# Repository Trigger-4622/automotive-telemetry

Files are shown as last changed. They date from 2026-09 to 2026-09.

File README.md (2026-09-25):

# Automotive Telemetry

A CAN-bus master and two gauge screens for a 2009 Subaru Legacy B4. The master
reads the car's CAN bus from the OBD port (listening, plus OBD-II and Subaru
SSM2 requests) and broadcasts engineering units over ESP-NOW. Any number of
screens listen and draw them.

```
 car CAN bus ──► master (ESP32-S3) ──ESP-NOW broadcast──► screen 1: round 1.28" (ESP32-C3)
 (OBD port)      reads, requests, learns                 └► screen 2: 4.3" dash cluster (ESP32-S3)
```

## Layout

| Folder | What it is |
|---|---|
| [`master/`](master/) | CAN master firmware: listen-first decoding, OBD-II + SSM2 requests, a learner that moves values onto broadcast frames, bus guard, web portal. [Bring-up guide](master/BRINGUP.md), [design blueprint](master/MASTER_NODE_BLUEPRINT.md). |
| [`screens/screen1-round/`](screens/screen1-round/) | Screen 1: ESP32-C3 with a 1.28" round GC9A01 touch display. [README](screens/screen1-round/README.md) |
| [`screens/screen2-cluster/`](screens/screen2-cluster/) | Screen 2: Guition JC4827W543, ESP32-S3 with a 4.3" 480×272 touch display. [README](screens/screen2-cluster/README.md) |
| [`scripts/`](scripts/) | `test_all.py` runs every test harness; `cloud-setup.sh` prepares a Linux machine or a Claude cloud session. |

Each firmware folder is a standalone PlatformIO project. They share one wire
contract, `include/MasterPacket.h`, which must stay byte-identical in all three.

## Build and flash

Needs [PlatformIO](https://platformio.org/). Each project builds on its own:

```bash
pio run -d master -t upload
pio run -d screens/screen1-round -t upload
pio run -d screens/screen2-cluster -t upload
```

A plain upload keeps each device's saved settings (the master's learned
signals, the screens' layouts and touch calibration). Do **not** run `uploadfs`
on the screens: it replaces their settings partition.

## Tests

Every project has a host test harness that compiles the unmodified firmware
for the PC: the master runs in a simulated car (CAN bus, ECU answering OBD-II
and SSM2, bus faults), and the screens render real LVGL into PNG screenshots.

```bash
python scripts/test_all.py            # everything
python scripts/test_all.py master     # or sync / screen1 / screen2
```

`sync` checks that the files the projects share are still identical and that
generated files (the master portal, the studio page) match their sources.
The harnesses need g++ and the libraries a first `pio run` downloads (or
`bash scripts/cloud-setup.sh --force` on Linux). GitHub Actions runs every
suite and builds all three firmwares on each pull request and push to `main`,
with a results table on the run page and the screen renders attached.

## Using Claude on GitHub

The repository is set up for Claude Code cloud sessions
([claude.ai/code](https://claude.ai/code)):

1. At claude.ai/code, connect GitHub and install the **Claude GitHub App** on
   this repository (it is private, so the app needs access to it).
2. Pick this repository and describe a task. Each session reads
   [`CLAUDE.md`](CLAUDE.md) for the project rules, and the session-start hook
   in `.claude/settings.json` runs `scripts/cloud-setup.sh`, so the host tests
   work in the cloud on the **Default** (Trusted) network setting.
3. For firmware builds in the cloud as well, edit the environment's network
   access: choose **Custom**, add `*.platformio.org`, and tick **Also include
   default list of common package managers**. PlatformIO downloads the ESP32
   toolchains from there.
4. Claude works on a branch and opens a pull request; CI builds and tests it.
   Turn on **Auto-fix** for the pull request and Claude also fixes failing
   checks and answers review comments.

Cloud sessions cannot reach your USB ports. To put a change on the hardware,
pull the branch on your PC and flash from there.

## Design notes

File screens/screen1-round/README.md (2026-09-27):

# Screen 1 — ESP32-C3 Round Telemetry Display (1.28")

Part of the [automotive-telemetry](../../README.md) system:

- **This screen** — an all-in-one ESP32-C3 board with an integrated
  1.28" circular GC9A01 IPS display and CST816S touch. Listens to an ESP-NOW
  broadcast firehose and renders fully configurable gauges (LVGL 8). No vehicle
  logic on board — 100 % driven by `layout.json` and a web-based Gauge Studio.
- **Master Node ([`master/`](../../master/), blueprint in
  [`MASTER_NODE_BLUEPRINT.md`](../../master/MASTER_NODE_BLUEPRINT.md))** — a classic ESP32 +
  CAN transceiver that parses the vehicle bus (OBD-II polling + raw DBC-style
  sniffing, incl. the electrical system) and broadcasts engineering units over
  ESP-NOW in multi-frame bursts (unlimited metric count, ≤250 B per frame).

The only shared coupling is the packed contract in
[`include/MasterPacket.h`](include/MasterPacket.h) — keep the copies in
`master/include/` and `screens/screen2-cluster/include/` byte-identical.

## Build & flash (Slave)

```bash
pio run -t upload
```

No filesystem upload: the Gauge Studio page is compiled into the firmware,
and a first boot writes a built-in layout by itself. For the full example,
paste `data/layout.json` into the studio's **Raw JSON** tab and Save.

> **Never run `pio run -t uploadfs` on a display in use.** It replaces the
> whole LittleFS partition - the layout, the uploaded backgrounds and (on the
> cluster) the touch calibration with it. Upload backgrounds from the studio's
> **Assets** tab instead.

Serial console runs on the board's native USB-C (115200).

> Uploads use `board_upload.before_reset = usb_reset`. This board talks over the
> C3's native USB-serial-JTAG, where the classic DTR/RTS auto-reset does not
> reliably enter download mode — without that setting, uploads fail with
> *"Wrong boot mode detected (0xc)"*.

> **Before first flash:** verify the pin map in
> [`include/HardwareConfig.h`](include/HardwareConfig.h) against your board —
> it is the single source of truth for every GPIO.

## Using the display

| Control | Action |
|---|---|
| Swipe left / right | Next / previous screen |
| Swipe up | Cycle day-night source: auto → forced day → forced night |
| Swipe down | Reset all peak values |
| Tap | Toggle peak-value display |
| Hold 5 s | Start config AP **Telemetry-Gauge-Config** → open `http://192.168.4.1` (Gauge Studio) |
| Hold 5 s (in config mode) | Reboot & apply |
| Side button, tap | Next screen (works with gloves) |
| Side button, 2.5 s | Same as the 5 s touch hold |

**If the side button does nothing**, it is on a different GPIO than assumed.
Swipe to the **DIAGNOSTICS** screen and watch the `GPIO` row while holding the
button — it lists the candidate pins live, e.g. `9H 8H 20H 21H`. The one that
flips to `L` is your button. Put that number in `global.button_gpio` in
layout.json (or the studio's Raw JSON tab) and reboot; no rebuild needed.

The default is GPIO9, the ESP32-C3 download strap. The strap is only read while
the chip resets, so it is free as a runtime input, and holding it while plugging
in USB still enters the ROM bootloader.

Gauge Studio lets you add/edit screens (arc gauges, needle tachometers, 2/4-way
splits, text lists, trend charts, diagnostics), map any metric ID, tune
colors/angles/thresholds with a live circular preview, upload background images
(LVGL `.bin`), and save the layout to the device.

## The watchdog (guard)

Two separate alarm paths, and it matters which one you edit:

| | Per-gauge `thresholds` | **Watchdog** (`watchdog.items`) |
|---|---|---|
| Where | On one screen | Global — its own **Watchdog** tab in the studio |
| Needs the metric on a screen | Yes | **No** |
| What happens | That widget recolors and pulses | A **warning triangle pops up over whatever screen is showing** |

The watchdog is the safety guard: give it a list of metrics with limits, and it
polices them all the time regardless of what you are looking at. The card names
the metric, its live value and the limit it broke. Critical pulses its border,
warning is steady. **Tap the display to acknowledge** and mute that one fault
for `global.alert_ack_ms` (default 30 s) — an escalation to critical, or a
second fault, re-arms it immediately, so muting can never hide something new.

Alarms are evaluated on the **raw** value rather than the smoothed display
value, with hysteresis so a reading sitting on a limit does not flicker.

**The pop-up is optional per metric.** Untick *Show pop-up alert* (or set
`"popup": false`) to police a metric silently. That is the right choice when
the metric already has a gauge whose red zone makes the fault obvious — a card
on top would only cover the reading you are trying to read. RPM ships this way,
since the tachometer already goes red at the redline. A silent item is still
evaluated and still counts toward the card's "+N more" badge.

## If transitions feel rough

`global.swipe_anim` picks the transition: `over` (default, cheapest — only the
incoming screen moves), `move`, `fade`, or `none` (instant, always perfectly
smooth). Shorten `swipe_anim_ms` too. The single most expensive thing you can
put on a screen is `background_asset` — LVGL re-reads file-backed images from
LittleFS on *every* repaint, so prefer `bg_grad` (free) or `texture`
(`carbon`/`mesh`, compiled into the firmware).

## Repository map

| Path | What it is |
|---|---|
| `platformio.ini`, `partitions_custom.csv` | Slave build config, 2 MB LittleFS partition |
| `include/HardwareConfig.h` | **All** pins & board constants (single source of truth) |
| `include/MasterPacket.h` | ESP-NOW data contract (metric registry, flags, packing) |
| `include/lv_conf.h` | LVGL v8 configuration |
| `src/` | `main` + `DisplayManager` `TouchManager` `NetworkManager` `ConfigManager` `UIBuilder` `TelemetryStore` |
| `data/layout.json` | Annotated example layout (dash, tach, coolant, electrical, powertrain, overview, diag) |
| `data/www/index.html` | Gauge Studio single-page app (compiled into the firmware by `tools/embed_studio.py`) |
| `data/assets/*.bin` | Uploadable backgrounds: carbon weave, brushed metal, HUD rings |
| `src/ui/Textures.h` | **Generated** — compiled-in textures and the GT dial face |
| `tools/make_assets.py` | Regenerates both (`python tools/make_assets.py`) |

## Look and feel

The default screens are styled as a GT / sports cluster: a near-black carbon
dial with a deep vignette, one red index at twelve o'clock, and white numerals
with a single warm and a single cool accent. Nothing else is bright, because
the needle and the numbers are what you actually read at a glance.

Two knobs control it, both per screen:

- **`dial_face`** — the drawn-on bezel rings and rim pips. Default on; the GT
  screens set it `false`, since concentric rings against black read as grid
  lines and fight the widget's own ticks.
- **`texture`** — `gt_dial` (full-screen carbon face), `gt` / `carbon` /
  `mesh` (32 px tiles), or `none`. All are **compiled into the firmware**, so
  drawing one is a blit with no filesystem in the path.

Contrast that with `background_asset`, which points at a LittleFS file: LVGL
re-reads file-backed images line by line on *every* repaint, so a 240×240
background costs ~115 KB of flash reads per full repaint. That mechanism still
exists for your own uploads, but nothing in the default layout uses it.

Regenerate or restyle the artwork by editing `tools/make_assets.py` and
running it — it emits both the compiled header and the uploadable `.bin`s.
| `../../master/MASTER_NODE_BLUEPRINT.md` | Full master-node engineering blueprint |
| `../../master/` | Standalone PlatformIO project: the master firmware |

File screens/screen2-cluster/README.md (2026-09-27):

# Screen 2 — ESP32-S3 4.3" Dash Cluster (480×272 landscape)

A second telemetry display node, alongside the 1.28" round board in
[`../screen1-round`](../screen1-round). Both listen to the
**same ESP-NOW broadcast from one master**, so they can run side by side in the
same vehicle — broadcasts reach every listener on the channel.

Hardware: **Guition JC4827W543C** — ESP32-S3-WROOM-1-N4R8 (dual core 240 MHz,
4 MB flash, 8 MB OSPI PSRAM), NV3041A 480×272 IPS panel on **Quad SPI**, GT911
capacitive touch.

## What differs from the round board

| | Round (1.28") | This board (4.3") |
|---|---|---|
| MCU | ESP32-C3, single core | ESP32-S3, dual core + 8 MB PSRAM |
| Panel | GC9A01, plain SPI | NV3041A, **Quad SPI** (4 bits/clock) |
| Touch | CST816S | **GT911** (16-bit registers, address latched at reset) |
| Canvas | 240×240 circle | 480×272 landscape rectangle |
| Flash | 4 MB, app got 1.875 MB | 4 MB **total** — 2.5 MB app / 1.4 MB filesystem |

The layout schema is otherwise identical: a `layout.json` written for the round
board loads here unchanged, it just will not use the extra room.

## Screen types

Shared with the round board: `arc_gauge`, `meter_gauge`, `quad`, `text_list`,
`chart`, `diag`.

Added here, because they need the width:

- **`cluster`** — the hero screen. Needle dial on the left, one dominant
  digital readout in the centre, and a stack of up to four secondary values
  down the right. Three regions, one glance each. Keys: `dial`, `main`,
  `side[]`.
- **`bars`** — up to six horizontal bar gauges stacked down the screen. The eye
  compares lengths along one axis far faster than it compares six separate
  numbers.

Also widened: `quad` takes up to **8 cells** (choosing 2, 3 or 4 columns from
the cell count, so six lays out as 3×2 rather than a 2×2 with holes),
`text_list` takes **10 rows** in two columns, and `diag` shows eight readouts
in two columns including **PSRAM** — which reads `NONE` if the module's memory
type is misconfigured.

## Build & flash

```bash
pio run -t upload
```

No filesystem upload: the Gauge Studio page is compiled into the firmware,
and a first boot writes a built-in layout by itself. For the full example,
paste `data/layout.json` into the studio's **Raw JSON** tab and Save.

> **Never run `pio run -t uploadfs` on a display in use.** It replaces the
> whole LittleFS partition - the layout, the uploaded backgrounds and (on the
> cluster) the touch calibration with it. Upload backgrounds from the studio's
> **Assets** tab instead.

## Board gotchas worth knowing

Three things cost real debugging time here; all are already handled in
[platformio.ini](platformio.ini), but they are the first places to look if a
fresh board misbehaves.

**Memory type.** The N4R8 module pairs *quad* flash with *octal* PSRAM. The key
that selects the right precompiled Arduino libraries is
`board_build.arduino.memory_type = qio_opi`. `board_build.psram_type` and
`board_build.memory_type` are **not read by this platform** and silently do
nothing.

**Flash size.** The `esp32-s3-devkitc-1` board definition assumes 8 MB; this
module has 4 MB. Left unset, the bootloader gets an 8 MB flash-size header and
the chip boot-loops — which presents as a USB CDC port that appears and
vanishes repeatedly and never becomes usable. Hence
`board_upload.flash_size = 4MB`.

**A LovyanGFX link error.** `Panel_NV3041A::init_cmds` is declared
`static constexpr` in the class but never defined out of class, which C++11
still requires when the symbol is odr-used. Linking fails with *"undefined
reference to init_cmds"*. [DisplayManager.cpp](src/hal/DisplayManager.cpp)
supplies the definition; delete that block if LovyanGFX fixes it upstream or
the toolchain moves to C++17.

**The GT911's "ready" bit is not "touched".** Status bit 7 means *a new
coordinate frame is available*, not *a finger is down*. The controller
refreshes at ~100 Hz and LVGL polls every 20 ms, unsynchronised, so plenty of
polls land between refreshes with the flag clear while the finger is still on
the glass. Treating that as a release chops one swipe into a burst of tiny
press/release pairs, none long enough to pass the swipe threshold — they all
classify as taps. [TouchManager](src/hal/TouchManager.cpp) holds the previous
state when the flag is clear and only believes a release when the controller
reports zero contacts.

If taps land in the wrong place or swipes go backwards, the digitiser is
mounted at a different orientation to the panel: fix it with `TOUCH_SWAP_XY`,
`TOUCH_INVERT_X` and `TOUCH_INVERT_Y` in
[HardwareConfig.h](include/HardwareConfig.h).

**`cfg.invert` is inert on this panel — use `invertDisplay()` instead.**
`Panel_LCD::setInvert` normally XORs the requested state with `_cfg.invert`,
which is how the flag works on the round board's GC9A01. `Panel_NV3041A`
*overrides* `setInvert` and sends `INVON`/`INVOFF` straight from its argument,
ignoring `_cfg.invert` entirely — and init always passes `false`. So the config
field does nothing whichever way it is set, which makes it a trap: it looks
like the control. Inversion is applied in
[DisplayManager::begin](src/hal/DisplayManager.cpp) via
`_gfx.invertDisplay(LCD_INVERT)`; this panel needs `LCD_INVERT = 1`. Symptom
when wrong: a white background with dark text while every position and
proportion stays correct, because inversion changes colour and never geometry.

### Stray pixels: four causes, in the order they were found

0. **The bus was not actually in quad mode.** LovyanGFX only ever *tests*
   `LGFX_USE_QSPI`; it never defines it. Without `-D LGFX_USE_QSPI` in
   `build_flags`, `Bus_SPI` never sets `_is_quad_spi`, quietly falls back to
   single-line SPI on `pin_mosi`, and leaves D1/D2/D3 unconfigured — while
   `Panel_NV3041A` carries on driving its quad protocol over one lane. The
   display half-works, which is the worst possible failure mode: it looks for
   all the world like marginal signal integrity. `pin_mosi` is now `-1`, since
   the four io pins are what matter once quad mode is on.

All three are fixed; they are listed because each produces the same symptom —
speckle scattered through freshly drawn elements — and knowing which is which
saves a lot of guessing.

1. **Transaction framing.** The round board holds a single `startWrite()` open
   forever and lets DMA pushes overlap, which is fine on plain SPI.
   `Panel_NV3041A` switches the bus in and out of quad mode around each
   transfer and manages its address window inside
   `beginTransaction`/`endTransaction`, so an outer transaction leaves that
   framing straddling transfers. Each flush now gets its own transaction.

2. **Buffer alignment.** A `static lv_color_t buf[]` is only guaranteed
   *2-byte* aligned — the natural alignment of its element type. SPI DMA wants
   its source word-aligned, and a half-word-aligned source yields sporadic
   wrong pixels rather than an honest failure. The buffers are now allocated
   with `heap_caps_malloc(..., MALLOC_CAP_DMA | MALLOC_CAP_INTERNAL)`.

3. **Odd-width windows.** LVGL invalidates the exact bounding box of what
   changed, so labels and arcs routinely produce odd `x1`/`x2`. An odd-width
   window leaves this controller's column counter half a word out of step with
   the 16-bit pixel stream, and everything after that point in the write lands
   a pixel adrift. A `rounder_cb` snaps every flush to an even column span.

**If speckle still remains,** it is signal integrity on the four data lines
rather than framing: step `LCD_SPI_HZ` in
[HardwareConfig.h](include/HardwareConfig.h) down to `26666667`. The ESP32
divides 80 MHz by integers, so the usable steps are 80, 40, 26.67 and 20 MHz —
asking for anything else silently rounds.

Uploads use `board_upload.before_reset = usb_reset`, same as the round board —
the classic DTR/RTS auto-reset does not reliably enter download mode on native
USB-serial-JTAG.

**Editing `data/` from PowerShell:** `Set-Content -Encoding UTF8` writes a
byte-order mark, and ArduinoJson rejects a BOM outright — `layout.json` then
silently falls back to the built-in default. Write those files with
`[System.IO.File]::WriteAllText($f, $text, (New-Object System.Text.UTF8Encoding($false)))`.

## Everything else

Controls, the watchdog, the Dash Studio portal, day/night, smoothing and the
ESP-NOW contract all behave exactly as documented in the round board's
[README](../screen1-round/README.md). `include/MasterPacket.h` must
stay **byte-identical** across the master and both displays.

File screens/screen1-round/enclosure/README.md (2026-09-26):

# Dash housing for the round display

A printed puck that holds the ESP32-2424S012 board (ESP32-C3, 1.28" GC9A01,
CST816S touch — the board screen 1 runs), floating on a slim stalk on the
dash top like a gauge pod. Everything is one parametric OpenSCAD file,
`round_display_housing.scad`; the STLs here are that file rendered with the
default numbers. `preview/` has renders of every part and of the assembly.

| File | What it is | Print |
|---|---|---|
| `testring.stl` | A 3 mm slice of the cup's cavity with the USB slot. **Print this first** (a minute). If the board drops in with a whisker of play and the USB plug clears the slot, the numbers are right. | flat |
| `cup.stl` | The puck: one piece, a 45° bevel round the face, no bezel ring, nothing on the front but the glass. The board goes in **from the back**, glass first, against the front lip and a foam ring. The USB-C plug leaves through a slot in the bottom of the wall, the two side buttons through two holes. | face down, no supports |
| `cover.stl` | The flat back. Three posts press the board forward onto the lip; three M2 countersunk screws into the wall; a shallow recess the stand's dock drops into, with two magnet pockets in its floor; vents in the upper half. | back down, no supports |
| `stand.stl` | The dash mount. A Ø40 foot with a VHB pocket underneath, a stalk that rises and bends back to lie in the puck's plane, and at its top a small dock with two magnets and a raised boss. The puck sits on the dock leaning back 12°; from the driver's seat nothing shows behind it. | foot down, no supports |
| `wedge.stl` | The alternative, lying down: a 20° wedge with a locating recess and the same dock boss, for a dash you look down at. | flat |

Default sizes: puck Ø48.5 × 16.1 mm. Standing, its centre is 36 mm above
the dash, its top 63 mm; the bottom edge is 9 mm clear of the foot for the
plug. Foot Ø40 × 3.5 mm, stalk 14 × 8 mm at the foot. The USB-C plug hangs
from the bottom of the puck with a **right-angle lead** whose cable goes
sideways past the stalk and back along the dash. About 30 g of filament in
all.

## Measure before you print the cup

The defaults come from the board's published outline (38.5 × 37 mm, Ø32.4
active area) and typical 1.28" display stacks — not from your board. Five
caliper measurements pin it down; each is a variable at the top of the file:

| Variable | Measure | Default |
|---|---|---|
| `board_d` | PCB diameter (the widest point) | 38.5 |
| `glass_d` | cover glass outer diameter | 36.0 |
| `front_stack` | glass top above the PCB's front face | 3.0 |
| `back_stack` | tallest part on the back (usually the battery socket or the radio module) | 5.0 |
| `usb_angle`, `btn_angles` | where the USB-C socket and the buttons sit. Hold the board the way the gauges read (the firmware does not rotate the picture, so the board's own "up" is up); angles run counter-clockwise from 3 o'clock, so 270° is straight down | 270, [200, 240] |
| `post_angles` | where the cover's three posts land. They press on the back face of the PCB, 1.4 mm in from its edge, so put them where that edge is bare | [30, 150, 330] |

If the board has flat edges, a round cavity still fits it (the flats just
leave a gap). Change the numbers, re-run the test ring, then export:

```bash
openscad -o cup.stl      -D 'part="cup"'      round_display_housing.scad
openscad -o cover.stl    -D 'part="cover"'    round_display_housing.scad
openscad -o stand.stl    -D 'part="stand"'    round_display_housing.scad
openscad -o wedge.stl    -D 'part="wedge"'    round_display_housing.scad
openscad -o testring.stl -D 'part="testring"' round_display_housing.scad
```

`part="assembly"` shows the puck on the stand; `part="exploded"` the parts
pulled forward off it. The stand's own knobs: `face_tilt` (how far it leans
back, 12°), `plug_gap` (clear height under the puck for the plug, 9 mm),
`stem_w`/`stem_d` (the stalk's section), `foot_d`. The puck's: `bevel` (the
face bevel, 3.5 mm) and `wall` (4.6 mm; the cover screws bite into it, so
not thinner).

## Printing

- **Not PLA.** A dashboard in the sun passes 70 °C and PLA slumps. PETG is
  the minimum; ASA or ABS is better. Matte black or dark grey, so the puck
  does not reflect in the windscreen.
- 0.2 mm layers, 3 perimeters, 20–30 % infill, no supports in the
  orientations above:
  - Cup face down: the bevel is a 45° overhang, the cavity opens upward, the
    USB slot runs out through the top of the print and the screw pilot holes
    are blind holes from the top, so nothing bridges.
  - Cover back down: the posts stand up; the dock recess, countersinks,
    magnet pockets and vents are holes in the first layers.
  - Stand foot down: the stalk never leans more than the 12° face tilt and
    widens gently behind the puck; the dock's boss is a 0.7 mm step.
- Screws: 3 × M2 × 8 countersunk self-tapping (ST2.2 × 8 flat head). The
  pilot holes are Ø1.8; run a screw in and out once before the board is in.

## Assembly

1. Two Ø10 × 2 mm disc magnets in the pockets at the bottom of the cover's
   recess, two in the dock's face, epoxy or thick CA, flush. **Check the
   polarity before the glue sets**: the pair in the dock must attract the
   pair in the cover. N42SH or ferrite if your summers are hot; ordinary N35
   loses strength above about 80 °C.
2. Stick a 1 mm foam ring (self-adhesive EVA, or three dabs of hot glue) on
   the glass edge, outside the display area. It takes up the tolerance in
   the stack height so the lip cannot rattle or crush the glass.
3. Board in from the back, glass first, USB-C socket lined up with the slot
   and the buttons with their holes. The glass lands on the foam against the
   lip.
4. Cover on. Its three screw holes are unevenly spaced, so it only lines up
   one way: with the USB slot at the bottom the dock recess is level. The
   posts land on the bare PCB edge; nothing touches the components. Three
   screws, snug, not tight.
5. Stand on the dash: clean the spot with isopropyl alcohol, a Ø34 disc (or
   a 30 × 30 mm square) of 3M VHB 5952 in the pocket under the foot, press
   hard for a minute, leave it 24 hours before hanging the puck on it. On a
   curved dash top, warm the tape with a hairdryer.
6. Puck onto the dock: the boss drops into the recess in the cover and the
   magnets pull it home. The boss takes the sideways loads (touching the
   screen, bumps), the magnets only have to hold it on. Right-angle USB-C
   plug in from below, cable out to the side past the stalk and back along
   the dash.

The puck lifts straight off the dock for flashing.

## What the defaults assume

- The USB-C socket points straight out of the PCB edge (side entry) and
  sits at the bottom when the picture is upright. If yours is elsewhere,
  set `usb_angle`; keep `screw_angles` and `post_angles` clear of it.
- The two buttons are side-actuated tactile switches at the PCB edge. If
  they are on the back face instead, set `btn_angles = []` and press them
  through a vent slot with a pin, or add pockets in `cover()`.
- The board's radio antenna is on the module itself; 3.6 mm of PETG behind
  it costs nothing noticeable. If yours has an IPEX pigtail antenna, tuck
  it into the gap between the components and the cover before closing.
- The lip covers 1.2 mm of glass edge and stays 0.6 mm clear of the active
  area. Touch works through the opening as before.

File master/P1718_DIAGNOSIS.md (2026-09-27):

# P1718 / P0700 — the check-engine light, diagnosed from the code

The car sets **P1718** ("AT CAN communication circuit": the transmission ECU
stopped receiving the engine ECU's CAN messages) and **P0700** (the TCM asking
for the lamp because of P1718). Both first appeared after the master was
installed, never before; the terminator on the transceiver module is removed;
the codes come back sometimes at the start of a drive and sometimes after 30
to 60 minutes of driving.

## Update 2026-09-27, later: where the errors come from - measure it on the next drive

With errors let pass the master can no longer destroy anyone's frame, but it
still misreads frames the rest of the car reads fine, and it still loses those
values. What the car has shown about that so far:

- Listen-only, before the TEC fix: about a million errors a session. Inflated
  (the controller counting its own unheard error flags); it says nothing about
  how often the master really misreads.
- Normal mode: the receive error counter went from 0 to 99-132 within
  13-150 ms of every switch - errors on a large share of frames.
- The evidence log: three brown-out resets. The 3.3 V rail sags hard at times.

What the search turned up (web, Espressif docs and issues, other projects):

- No ESP32-S3 TWAI erratum beyond the listen-only one (fixed). The S3 cannot
  read CAN FD frames - irrelevant on a 2009 car.
- "Long critical sections or higher-priority interrupts cause bus errors" (an
  Espressif-side remark): on this controller a late interrupt loses frames to
  a FIFO overrun; it cannot corrupt bits on the wire. Not the cause.
- arduino-esp32 #9191 (S3; one message always failed; the Arduino-CAN timing
  worked) is still unresolved upstream. Its timing is the default here
  (`can_timing` 2), not yet tried on the car.
- The "GPIO5 breaks Wi-Fi" report is an ESP32-S2 custom board, not this DevKit.
- The firmware never changes the CPU or APB clock: the CAN bit rate cannot drift.
- Wi-Fi transmit current spikes sag an ESP32's 3.3 V rail - the usual cause
  of brown-outs - and the SN65HVD230 is specified down to 3.0 V only. The
  master's own radio making its transceiver misread fits the brown-outs.

The causes left, and what tells them apart:

| Cause | Missed frames | Errors vs the radio | Normal vs listen-only |
|---|---|---|---|
| 3.3 V rail sagging under the radio | every module's IDs | far above chance | the same |
| The tap: stub, ground, transceiver Rs pin | one module's IDs more than others | chance | the same |
| The master's own transceiver driving the bus (ACK) | every module's | chance | more in normal mode |
| Bit timing against this bus | frames with long runs of equal bits (some IDs) | chance | the same |

Two measurements now give those columns, on the Bus tab under "What the
errors are" → "Where they come from" (and a `[link ]` serial line):

- **Missed frames per ID and mode** (`missAccount`). The car's broadcasts are
  periodic, so a gap of whole periods in an ID is a frame the master misread.
  Anything that makes the master deaf for a moment - a flash write (the CAN
  interrupt waits for it), a TEC write, a reinstall, a full queue - calls
  `masterBusBlind()`, and a gap across it is not counted. Simulator: every
  missed frame was a real misread (a clean link: 0 of 6 411), in listen-only
  and normal mode alike (`link_misses`).
- **Bus errors against the radio** (`radioNoteErrors`): the share of errors
  while an ESP-NOW broadcast was on air or within 3 ms of it, against the share
  of the time the radio is that busy. Simulator: a link fault lands near the
  radio by chance (9.8 % against 11.1 %); a radio that disturbs the CAN side
  puts 100 % of its errors there against 14 % (`link_radio`).

The simulator's car now sends on its own clock, 0.5 % off the master's, as
separate crystals do; on one shared clock the radio locked to the car's
frames. That exposed a learner weakness: a switch sample right after a flip
could pair the new state with a frame still showing the old one, and whether
a flip cost the sample before or after it depended on how they lined up - the
brake switch matched at phi 0.960 against the 0.95 needed. Both are dropped
now; it matches at 1.000.

**Test plan for the next drive** (errors let pass, requests on):

1. 10 minutes driving. Screenshot the Bus tab card.
2. Advanced → Radio transmit power 2 dBm; 10 more minutes; screenshot. (The
   displays sit a metre away; 2 dBm reaches them.)
3. Optional: Settings, both requests off (listen-only) for 10 minutes;
   screenshot.

If the errors sit near the radio, or fall at 2 dBm: the supply - give the
transceiver its own clean 3.3 V (or a low-noise LDO) and decouple it
(10 µF + 100 nF at its pins). If the misses concentrate on a few IDs: that
module's link at the tap - stub length, ground to OBD pin 5 (signal ground),
Rs pin to GND. Neither: `can_timing` 1 or 0 for a drive, to compare.

## Update 2026-09-27: "let errors pass", from the first bit

Passive transmit mode is now called what it does: **Let errors pass**
(`tx_passive`, on by default) - the master never sends an error frame. A frame
it reads as bad it drops for itself; the other modules acknowledge it and it
reaches them untouched. The normal acknowledgement of good frames is unchanged.

It had one gap: `twai_start()` clears the error counters, so for the moment
between starting the controller and setting TEC it was error-active - at boot,
after the settle wait, after a bus-off restart and on every return from
listen-only. The simulator now counts every moment the controller is on the
bus able to send an active error flag, and found the gap three times in one
drive (`error_frames_never`). `twaiGoLive()` closes it: the TX pad stays a
recessive GPIO while the controller starts, and goes back to it only once TEC
is set. Result: zero.

The portal's **Safe bus settings** (Maintenance) puts the bus behaviour alone
back to the defaults - requests on (Auto), errors let pass, 87.5 % with triple
sampling, both guards, P2CAN 50 ms, the 10 s wait after power-on - and keeps
the bitrate, the request pacing, the displays, Wi-Fi and every learned value.
Factory reset clears learned values too; its prompt now says so.

## Update 2026-09-26, night: passive transmit mode - transmit without ever destroying a frame

A node cannot be told to stop acknowledging while it transmits: in Espressif's
words only listen-only disables acknowledgements, and it disables transmitting
with them; "no-ACK" mode only stops *requiring* an acknowledgement. Nor can a
node acknowledge "only if another module does" - every receiver drives the same
single ACK bit at the same moment. But the acknowledgement was never the harm:
the master acknowledges only frames it received correctly, and a dominant ACK
merely joins the others'. The harm is the **active error flag** it sends for a
frame it thinks is bad.

An **error-passive** node (TEC or REC >= 128) sends only passive, recessive
error flags, which cannot destroy anyone's frame - while it still transmits,
receives and acknowledges. REC cannot hold it there (every good frame winds
REC down), but TEC only moves when the node itself transmits. So **passive
mode** (`tx_passive`, on by default) sets TEC to 220 whenever the controller
starts in normal mode, and before each request tops it back up if the
master's own successful frames have brought it below 170 - four transmit
errors of headroom before bus-off at 256. With it, the receive-error guard
stands down: there is nothing left for it to protect. In the simulator, a link
misreading 30 % of the engine ECU's frames - far worse than the car - with the
car's own settings: 4 783 misreads, 0 frames destroyed, the ECM never bus-off,
no P1718, and OBD-II requests running throughout (`passive_marginal`).

## Update 2026-09-26, evening: the errors were being miscounted, and the timing

With the erratum fix on, the car behaved in silent mode, but the portal showed
**1 021 263 bus errors in one session** with the master listen-only - about
one per frame at 1 174 frames/s - and **error counters 0 / 0**. The MIL came
back whenever the master was allowed to transmit.

**The count was inflated, by the listen-only fix itself.** A controller that
really misread that many frames would have lost them (it received all 1 174/s)
and its REC would have climbed. REC 0 in listen-only means the REC 128 set at
start did not hold - a good frame winds REC down - so the controller was
error-active again, and with its TX pad detached it read its own error flag
back recessive, took that for a bit error, flagged again, and counted every
round. Now `listenOnlyErratumFix()` also sets **TEC to 128**, which cannot move
in listen-only (it only changes when the controller transmits), so the
controller stays error-passive. In the simulator, with REC drifting as on the
car, 887 misreads now count as 887 errors; without the TEC write, 6 923
(`lom_rec_drift`).

**The real errors, in normal mode, point at the bit timing.** Every switch to
normal mode took REC from 0 to 99-132 within 13-150 ms (the evidence log): the
controller finds fault with nearly every frame the moment it takes part - and
in normal mode each fault is an error flag that destroys the frame for the
whole car. The firmware used the ESP-IDF preset for 500 kbit/s: sample point
80 %, SJW 3, **one sample per bit**. Vehicle buses are specified at 87.5 %
(SAE J1939/J2284), and the Arduino-CAN library programs the ESP32 for 500
kbit/s at 87.5 %, SJW 2, with **triple sampling** (three samples, majority
vote, so a spike or ringing edge is outvoted). arduino-esp32 issue #9191 is an
ESP32-S3 on a car where the ESP-IDF driver produced bus errors into bus-off
while Arduino-CAN on the same hardware did not. That profile is now the
default: **`can_timing` 2** (1 = 87.5 % single sample, 0 = the ESP-IDF preset;
your stored `can_sp875` is kept and only applies with 0).

**No more guessing: the controller now says what each error is.** The TWAI
error-code-capture register holds the type, direction and frame segment of
the latest error; it is sampled on every error and tallied per mode - portal
Bus tab "What the errors are", and `[errs ]` lines in the serial log. Bit
errors *while sending* in the ACK slot mean our own transceiver is not driving
the bus properly (its supply - the master has browned out three times in the
car - its ground, or its mode pin: the SN65HVD230's pin 8 must go straight to
ground; through 100 kΩ its loop delay is up to 920 ns, and pulled high its
driver is off). Stuff, form or CRC errors *while receiving* mean the link or
the timing.

**Radio power** now defaults to 13 dBm (`radio_dbm`): the displays are a metre
or two away, and a lower power draws smaller current bursts from the supply
the transceiver shares.

**Next drive:** after the flash, stay listen-only a few minutes and read "What
the errors are" (now an honest count), then switch to OBD-II with the
receive-error guard **on** and read it again. If normal mode still collects
errors, the table says which of the causes above it is.

## Update 2026-09-26: why the first fix made it worse

After the flash the car showed 100 000+ bus errors with the master
listen-only, and the MIL came on sooner than with the firmware before. With
the master unplugged: no MIL. The cause is in the ESP32-S3 itself.

**Espressif's listen-only erratum.** On the ESP32, S2, S3 and C3, a TWAI
controller in listen-only mode still transmits an *active* error flag - six
dominant bits, which destroy the frame for every module - whenever it detects
an error in a frame. Listen-only also *freezes* the error counters, and
`twai_start()` leaves REC at 0, so the controller stays error-active for as
long as it listens. ESP-IDF has a fix (`CONFIG_TWAI_ERRATA_FIX_LISTEN_ONLY_DOM`,
"not set" in the Arduino core's `sdkconfig`), and its Kconfig help names the
ESP32-S3 among the chips whose listen-only controller still sends dominant
error bits (ESP-IDF v4.4.7, `components/driver/Kconfig` and
`components/hal/twai_hal.c`, `twai_hal_start`).

**Why that is worse than normal mode.** CAN's fault confinement is built so
that a node which alone sees errors backs off: each of its error flags adds 9
to its REC while the sender's TEC gains 8, so within ~15 tries it is
error-passive (its flags become recessive and harmless) - long before the
sender reaches bus-off at 256. With REC frozen at 0 that never happens: the
master destroys every retransmission of a frame it misreads and the *sender*
- the engine ECU - is driven bus-off. The TCM loses the ECM: P1718, at once.

**Why the first fix walked into it.** The settle wait (listen-only for 10 s at
every start) and the receive-error guard (listen-only for the rest of the
drive once the master misreads frames) both used listen-only as the safe
place. On a link where the master misreads frames - which the guard tripping
proves this one does - that made the master destroy the ECM's frames from the
first misread onward. The firmware before stayed in normal mode, where fault
confinement limited the damage: it needed frequent misreads to add up, hence
"30 to 60 minutes".

**The fix** (`listenOnlyErratumFix()` and `setupTwai()` in `src/main.cpp`):
Espressif's workaround - REC set to 128 in reset mode right after
`twai_start()`, error-passive and frozen there - and, on top, the TX pad taken
away from the controller and held recessive for as long as it listens, so
nothing it does can reach the transceiver. The TX pin is now always set level
first, output second (the old `pinMode`-then-`digitalWrite` put a dominant
glitch on the bus at every boot), and the pad leaves the controller before
the driver is stopped or uninstalled.

**Also fixed:** the P2CAN wait counted from when the poller asked for the bus,
not from when the request went out; in AUTO an SSM2 exchange holds the bus
first, so with the car's current `obd_to` 25 / `obd_gap` 20 the gap behind an
unanswered request was 45 ms, not 50 (`pacing_p2can_auto`).

**Proof in the simulator**, which now models the erratum, frozen counters, TX
pad routing and CAN fault confinement (the ECM goes bus-off at TEC 256 with
quick-then-slow recovery): on the firmware as flashed, `tcm_p1718` shows the
guard switching to listen-only and then the ECM driven bus-off about once a
second - 5 993 attempts destroyed, P1718 - and `rx_guard_prompt` shows the ECM
bus-off within 10 ms during the settle wait. With the fix: listen-only on a
marginal link destroys nothing (`lom_erratum_silent`: 887 misreads seen, 0
destroyed, no P1718) and a full drive with the car's settings costs at most
one burst at the first normal-mode misread (`lom_erratum_drive`).

**What remains is physical.** The master misreads frames the rest of the car
reads fine - that is what trips the guard. The listen-only error count in the
portal is now an honest measure of it (one error per misread, no cascade).
The wiring checks in the flash checklist, and the 87.5 % sample point
(`can_sp875`), are the ways to bring it down.

---

This file is the diagnosis, what was changed, the flash checklist and the
test plan. The simulator work is in `test_host/tests/scenarios.cpp`
(`tcm_p1718` and the scenarios after it) and the firmware changes in
`src/main.cpp` and `src/MasterConfig.*`.

## Ranked causes and the evidence for each

The question is narrow: what can the master do that takes the engine ECU's
broadcast frames away from the transmission ECU?

**1. Error signalling in normal mode on a marginal link (suspect 2) — most likely.**
In normal mode the CAN controller does not only transmit: it ACKs every frame
and, when *it* detects a bit, stuff, CRC or form error in *any* frame, it
transmits an error flag, which destroys that frame for every module on the
bus — the TCM included. If the master's link is marginal (stub, ground,
sample point), it sees errors in frames the rest of the bus receives fine, and
in normal mode it actively signals them. Nothing in the firmware watched for
this: the bus guard only ever looked at the transmit error counter (errors in
*our* frames), and it is turned off in the car's settings anyway. A rising
*receive* error counter — the controller telling us it is flagging errors in
frames it only receives — went unseen. Evidence: the codes never appeared
before the install; they come back after long drives, a sustained-operation
signature rather than a boot one; the portal showed 61 bus errors and the bus
"felt unstable" under heavy SSM2. In the simulator, with the car's own
settings file and a marginal link, the TCM sets P1718 within seconds; with the
new receive-error guard it never does. Listen-only mode cannot send an error
flag or an ACK, which is why it is the fallback.

**2. A reboot during cranking, with the TX line not held recessive (suspects 3 and 4).**
Sleep is disabled, so the master is powered through every crank on the
always-live pin via the buck converter; a voltage dip that browns the ESP32
out restarts it while every module on the bus is starting. Two things follow.
The settle wait that would keep it listen-only for those seconds is not on the
car yet. And nothing held GPIO 5 (transceiver TXD) recessive across the reset:
if TXD floats or sits low while the chip is down, the transceiver drives the
bus dominant and jams it. There was no record of reset reasons, so this could
never have been seen. Evidence: the "at the start of a drive" recurrences.
What the simulator shows: a brown-out boot is now recorded, the settle wait
holds the controller listen-only for 10 s after the bus comes up, TX is driven
recessive the instant the firmware runs and latched recessive across sleep.
What only the car can show: whether the buck actually drops out at cranking
(the evidence log's boot reasons will say), and whether TXD floats low during
reset (a 10 kΩ pull-up from TXD to 3V3 covers it whatever the answer).

**3. Request pacing below P2CAN with no ceiling (suspect 1).**
`obd_to` is 20 ms; ISO 15765-4 gives the ECU 50 ms (P2CAN) to answer. An
answer at 35 ms was timed out at 20 ms and, with `obd_gap` 10 ms, the next
request went out 30 ms after the last — into the reply the ECU was still
sending. And with 66 PIDs enabled at periods down to 50 ms there was no
overall cap. On its own this does not take frames from the TCM (0x7E0 loses
arbitration to 0x231), but it is a steady source of exactly the errors that
cause 1 turns into destroyed frames. Simulator: with a 35 ms ECU the gap
between requests was 30 ms; it is now at least 50 ms, and the stored `obd_to`
is untouched.

**4. Functional 0x7DF requests reaching the TCM (suspect 5) — low.**
On this car the engine ECU answers physical 0x7E0, so the steady state was
already physical-only. But with addressing on auto, one missed physical probe
switched the master to 0x7DF for the rest of the session — and the TCM answers
0x7DF. Simulator: a transient miss now leaves it physical; before, it did not.

**5. Not software (suspect 6).**
The terminator is confirmed removed, which takes the commonest hardware cause
off the list. Stub length, the transceiver ground and the sample point cannot
be judged from here — they are what makes cause 1 fire, and the evidence log
and step 1 of the test plan tell them apart from a plain car fault.

## What changed

Everything is an addition. Nothing the master did on the bus is removed or
reduced; every measure has a switch and a value in the portal (Settings or
Advanced), and every stored setting and learned signal survives: the
`device_config` scenario replays the car's file and still shows 0
differences. `CFG_VERSION` stays at 5. No stored value is overridden — in
particular **`obd_to` stays at 20**: rather than raising it to 50, a separate
post-timeout wait (`obd_p2can`) was added, so the reply wait you chose is
kept and the ISO spacing is enforced on top. Raise `obd_to` yourself if you
prefer that.

| Fix | Setting (default) | What it does | Scenario |
|---|---|---|---|
| Receive-error guard | `rx_guard` (on), `rx_guard_rec` (96), `rx_guard_errs` (60 in `guard_win`) | Switch to listen-only for the session when the controller is error-flagging other modules' frames: either its receive error counter reaches the error-warning level (a storm), or that many receive-side errors land in the guard window (a *moderate* marginal link, which never raises REC because a good frame winds it down faster than a flagged one winds it up). Also on bus-off while the transmit-side `guard` is off. Independent of `guard` (which stays off as you set it). Resume from the portal. | `tcm_p1718`, `tcm_p1718_optout`, `rx_guard_trickle`, `rx_guard_moderate`, `rx_guard_prompt`, `busoff_guard_off` |
| P2CAN wait | `obd_p2can` (50 ms) | After a request that got no answer within `obd_to`, the next request waits until this long after the send. Delays, never drops. | `pacing_p2can` |
| Request budget | `req_max_hz` (0 = off) | Ceiling on OBD-II requests per second; spreads them, never drops. Off by default so nothing is throttled that you did not choose; 40 is a sensible value for the car. | `budget` |
| Settle wait | `start_delay_s` (10) | Already built; this branch puts it on the car. Listen-only for 10 s each time the bus comes up. Absent from the stored file, so it takes the default. | `settle*`, `crank_reset` |
| Physical addressing latch | (none: behaviour) | Auto addressing gives physical several tries before ever using 0x7DF, and never goes back once physical has worked. | `no_functional` |
| TX recessive hold | `tx_hold` (on) | GPIO 5 driven recessive the instant the firmware starts (always) and latched recessive across deep sleep (this switch). | `tx_hold`, `tx_hold_off` |
| Evidence log | Diagnostics tab, `/api/evlog` | Boot and reset reasons, bus up, settle end, guard trips with the error counters and what we were transmitting, bus-off, sleep. Kept in `/evlog.json` on LittleFS across reboots and updates. | `crank_reset`, `evlog` |

Three more things the audit of the guard task turned up and fixed, each
with a scenario:

- The controller's switch *to* listen-only used to wait for the 2 s
  mode-switch throttle. The likeliest trip is in the first normal-mode
  contact with a marginal link, right after the settle wait ends - which is
  inside that 2 s. The switch towards listen-only is now immediate; only the
  way back is throttled (`rx_guard_prompt`).
- Bus-off with the transmit guard off - the car's setting - used to recover
  and carry straight on. Bus-off is the protocol throwing us off after 32
  failed frames, each an active error flag on the bus; carrying on does it
  again. It now latches listen-only until Resume (`busoff_guard_off`). With
  both guards off it carries on as before (`guard_off`).
- REC alone misses a moderate marginal link (see the table); the error rate
  in the guard window catches it (`rx_guard_moderate`).

The simulator gained a transmission ECU that watches the engine ECU's
broadcasts (0x231, 0x232 stand in for them) and latches P1718 when fewer than
30 of the ~150 expected arrive in 1.5 s on a live bus; a marginal-link fault
under which a normal-mode master corrupts a fraction of those frames (and its
REC rises, as a real controller's does); REC that winds down on good frames;
and mocks for the reset reason and the GPIO hold.

`tcm_p1718_optout`, the `obd_p2can: 0` phase of `pacing_p2can` and
`tx_hold_off` run each fix switched off: they are the pre-fix behaviour,
reproduced and kept in CI — the TCM sets P1718, the requests crowd the ECU,
the TX line is not latched.

## What could not be confirmed without the car

- That the link is marginal at all. The receive-error guard's trips in the
  evidence log, or a listen-only drive with no lamp, are the confirmation.
- That the ESP32 browns out at cranking. The evidence log's boot reasons say.
- That the transceiver's TXD floats low during reset. Hardware; fit the
  pull-up regardless.
- The real TCM's P1718 criteria and which frames it needs. The model uses the
  RPM and throttle frames the learner found and a threshold that trips on a
  real gap, not on a stray loss.

## Flash checklist (on your PC)

1. `git fetch`, check out the branch that holds the change, `git pull --ff-only`.
2. Full backup first: `esptool.py --chip esp32s3 read_flash 0 0x1000000 master-backup.bin`,
   then `esptool.py --chip esp32s3 verify_flash 0 master-backup.bin`.
3. Check the partition table the build uses matches the board
   (`platformio.ini`: 16 MB, LittleFS) — a wrong one boot-loops.
4. Plain `pio run -d master -t upload`. Never `uploadfs`.
5. Read the settings back: open the portal, Advanced → "Everything, as JSON"
   → Download, and compare with the `config.json` taken out of step 2's backup
   (`python tools/littlefs_read.py` on the LittleFS partition) - the same
   values, signal for signal. Before the upload, `device_config` with
   `DEVICE_CONFIG=<that file>` shows the new firmware loads it with 0
   differences.
6. Hardware while you are there: a 10 kΩ pull-up from the transceiver's TXD
   to 3V3; the transceiver GND to OBD pin 4/5; stub under 30 cm.
7. Portal → Settings: "Receive-error guard" on (it is, by default); Advanced:
   `req_max_hz` 40 if you want the budget. Diagnostics → Clear.
8. First start: the portal pill says "settling · N s" for 10 s, then "live".

What is different on the car after the flash, without touching your file:
the 10 s settle wait, the receive-error guard, the 50 ms post-timeout wait
and the TX hold are on; the evidence log runs. `obd_to` 20, `obd_gap` 10,
`guard` off, `sleep_enabled` off and `obd_addr` auto are as you left them.

## Test plan — one step per couple of days, clear the codes before each

**1. Master unplugged.** Codes come back → the car has a fault of its own and
the master is not it; stop here. No codes → the master is involved; go on.
(Flash this branch now, so steps 2–4 have the evidence log.)

**2. Listen-only** (Settings: both request switches off; the pill says
"listening only"). The controller cannot transmit, ACK or send an error flag.
No codes → an active-mode behaviour is the cause (1, 3 or 4 above); go on.
Codes anyway → only the reset window is left on our side: open Diagnostics
and look for brown-out boots; fit the pull-up if it is not on; if the log shows
clean power-ons only, it is the wiring or the car (back to 1).

**3. OBD-II with the fixes** (Settings: OBD-II on, SSM2 off — the mode as
today). After every drive read Diagnostics. Receive-error guard trips → cause
1 confirmed: the link is marginal; fix the ground and stub, try the late
sample point (Advanced, reboot), and the guard has meanwhile kept the TCM
safe. Brown-out boots → cause 2 confirmed; the settle wait covered it. No
trips, no brown-outs, no codes → fixed; go on. Codes with a clean log → lower
`rx_guard_rec` (64) and set `req_max_hz` 40, repeat.

**4. SSM2 on** (Settings: both on; mode Auto). Codes only now → the SSM2
traffic pattern is the trigger: keep OBD-II only, or raise `ssm_gap` and lower
`ssm_batch`. No codes → done, everything on.

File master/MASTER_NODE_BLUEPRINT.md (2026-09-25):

# Master Node Blueprint — Automotive CAN → ESP-NOW Telemetry Bridge

**Version 1.0 · Protocol v1 · Companion firmware to the ESP32-C3 Round Telemetry Display**

This document is the authoritative engineering blueprint for the **Master Node** ("Data
Firehose"): a vehicle-mounted ESP32 that reads the CAN bus, parses raw frames into
standardized engineering units, and broadcasts them continuously over ESP-NOW to any
number of display slaves. A complete, buildable reference implementation ships in
this folder ([`platformio.ini`](platformio.ini)) — this document explains every design
decision behind it.

---

## 1. Design Doctrine — Separation of Concerns

| | Master ("Data Firehose") | Slave ("Intelligent Canvas") |
|---|---|---|
| Knows the vehicle | **Yes** — CAN IDs, PIDs, scaling formulas | Never |
| Knows the UI | Never | **Yes** — layout.json, gauges, thresholds |
| Radio role | Broadcast-only transmitter | Receive-only listener |
| Adding a display | No change | Just power it on |
| Changing vehicles | Edit `CanDecoderConfig.h` only | No change |

The only coupling between the two firmwares is **`MasterPacket.h`** — a packed binary
contract. One copy lives in each project (`master/include/MasterPacket.h` and
`screens/*/include/MasterPacket.h`); **they must remain byte-identical**.

```mermaid
flowchart LR
    subgraph Vehicle
        ECU[ECU / OBD-II]
        IBS[Battery sensor / BCM]
    end
    subgraph Master["Master Node (ESP32 + SN65HVD230)"]
        TWAI[TWAI RX task]
        OBD[OBD poll task]
        STORE[(Metric store<br/>64 slots)]
        BC[Broadcast task 20 Hz<br/>multi-frame bursts]
    end
    subgraph Slaves
        S1[Round display 1]
        S2[Round display 2]
        S3[...]
    end
    ECU -- "CAN 500k" --> TWAI
    IBS -- "CAN frames" --> TWAI
    OBD -- "0x7DF requests" --> ECU
    TWAI --> STORE --> BC
    BC == "ESP-NOW FF:FF:FF:FF:FF:FF<br/>channel 1" ==> S1 & S2 & S3
```

---

## 2. Hardware

### 2.1 Bill of Materials

| Part | Purpose | Notes |
|---|---|---|
| ESP32 DevKit (classic, dual-core) | Bridge MCU | Built-in TWAI (CAN 2.0) controller |
| SN65HVD230 **or** TJA1051/3 | CAN transceiver | 3.3 V logic — **do not** use 5 V-only TJA1050 without level care |
| Buck converter 12 V → 5 V (automotive-rated) | Power | Must survive load-dump transients; add a 500 mA fuse tap |
| OBD-II male connector / pigtail | Bus access | Or a branch splice on a body harness |
| Optional: LDR + 10 kΩ divider | Night detection | See `NIGHT_SOURCE` in config |

### 2.2 Wiring

| ESP32 pin | Signal | Goes to |
|---|---|---|
| GPIO 5 (`CAN_TX_GPIO`) | TWAI TX | Transceiver **CTX/TXD** |
| GPIO 4 (`CAN_RX_GPIO`) | TWAI RX | Transceiver **CRX/RXD** |
| 3V3 | Power | Transceiver VCC |
| GND | Ground | Transceiver GND **and** vehicle chassis ground |
| — | CANH | OBD-II **pin 6** |
| — | CANL | OBD-II **pin 14** |
| VIN (5 V) | Power | Buck output (input: OBD-II pin 16 = +12 V batt, pin 4/5 = GND) |
| GPIO 34 (`NIGHT_LDR_GPIO`) | ADC | LDR divider midpoint (optional) |

**Termination:** the vehicle bus is already terminated (2 × 120 Ω). The bridge is a
*stub* — leave the transceiver's 120 Ω termination **disabled/unsoldered**. Only enable
it on a bench bus you build yourself.

**RS pin (SN65HVD230):** tie to GND for high-speed mode.

### 2.3 Safety rules (non-negotiable)

1. **First contact with any vehicle is LISTEN-ONLY** (`OBD_POLLING_ENABLED 0`,
   `TWAI_MODE_LISTEN_ONLY`). The controller never ACKs, never transmits, and is
   electrically incapable of corrupting bus traffic.
2. Enable OBD polling (`NORMAL` mode) only on the diagnostic bus behind the OBD port,
   never on a spliced body/chassis bus you don't fully understand.
3. Bench note: a listen-only node on a 2-node bench bus means **nobody ACKs** — the
   transmitter will retry endlessly. For bench work either use NORMAL mode or add a
   third acking node.
4. The firmware self-heals from bus-off (`twai_initiate_recovery()` in the
   housekeeping task) so a transient short never bricks the bridge.

---

## 3. The Data Contract (`MasterPacket.h`)

### 3.1 Wire format

```
MasterTelemetryPacket (packed, little-endian):
┌──────────────┬──────────────┬──────────────┬─────────────────────────────┐
│ sequence_id  │ timestamp_ms │ metric_count │ metrics[metric_count]       │
│ uint32 (4 B) │ uint32 (4 B) │ uint8 (1 B)  │ metric_count × 7 B          │
└──────────────┴──────────────┴──────────────┴─────────────────────────────┘
MetricEntry (7 B):  uint16 metric_id · float value · uint8 flags
```

- Header = 9 B; a full frame of 28 metrics = **205 B ≤ 250 B** (ESP-NOW hard limit),
  enforced by `static_assert`.
- Only the *used* portion is transmitted: `TELEMETRY_PACKET_SIZE(metric_count)`.
- Slaves validate with `telemetry_packet_valid()` before touching a byte.

### 3.2 Scaling beyond 28 metrics — multi-frame bursts

ESP-NOW v1 frames cap at 250 bytes. ESP-NOW v2 (IDF 5.x) allows 1490 B **but silently
falls back to 250 B when any v1 peer participates** — a trap, not a feature. The
contract therefore scales by **bursting**:

- Every broadcast cycle, the master chunks all fresh metrics into as many frames as
  needed (`broadcastTask` in the reference code), each ≤ 28 entries.
- Each frame is fully self-describing with its own incrementing `sequence_id`.
- A metric appears in exactly one frame per burst; slaves merge frames by `metric_id`
  into their store, so **the total channel count is unbounded** (the reference
  implementations size their stores at 64 on both ends — raise both if you need more).
- Slave drop statistics still work: gaps in `sequence_id` count lost frames whether
  frames travel alone or in bursts.

### 3.3 Flags

| Bit | Name | Semantics |
|---|---|---|
| 0 | `VALID` | Value fresh & trustworthy; slaves render `--` when clear |
| 1 | `WARNING` | Master threshold table crossed — yellow tier |
| 2 | `CRITICAL` | Master threshold table crossed — red tier |
| 3 | `NIGHT` | Vehicle in night mode (set on **every** entry of a frame) |
| 4–7 | reserved | Transmit as 0 |

Master flags are a *safety floor*: the slave's own configurable thresholds can escalate
an alarm but never suppress a master-flagged one.

### 3.4 Metric ID registry

The 16-bit ID space (full list with mandatory units in `MasterPacket.h`):

| Range | Domain | Examples |
|---|---|---|
| `0x01xx` | OBD-II Service 01 (low byte = PID) | `0x010C` RPM, `0x0105` Coolant °C, `0x0142` Battery V |
| `0x02xx` | OBD Service 22 / manufacturer extended | project-defined |
| `0x10xx` | Raw-CAN powertrain/chassis | `0x1001` Boost bar, `0x1004` EGT °C |
| `0x11xx` | **Raw-CAN electrical system** | `0x1101` Battery A, `0x1102` SOC %, `0x1105` Alternator V, `0x1108` 12 V rail, `0x1109` Total load W |
| `0x1Fxx` | Housekeeping | `0x1F01` night sense, `0x1F02` master uptime |

Values are **always broadcast in the registry's mandated engineering unit** (°C, bar,
V, A, %, km/h…). All vehicle-specific scaling happens on the master; a slave layout is
therefore portable across cars.

### 3.5 Radio parameters

- Broadcast MAC `FF:FF:FF:FF:FF:FF`, no pairing, no encryption (broadcast frames
  cannot be encrypted in ESP-NOW).
- **`TELEMETRY_WIFI_CHANNEL` (default 1) must match on master and slave** — it is part
  of the contract. Broadcast delivery is fire-and-forget (no ACK for broadcast), which
  is exactly right for a firehose: late data is worthless, the next frame is 50 ms away.
- Versioning: breaking struct changes bump `TELEMETRY_PROTO_VERSION` and require
  flashing both nodes. New metric IDs are always non-breaking.

---

## 4. CAN Acquisition — Two Complementary Strategies

### 4.1 Strategy A: OBD-II active polling (`OBD_POLL_TABLE`)

For any 2008+ vehicle, Service 01 PIDs are the reliable baseline. The engine sends
single-frame requests to the functional address **0x7DF** and parses replies from
**0x7E8–0x7EF**:

```
Request : 0x7DF  [02 01 <PID> 55 55 55 55 55]     (ISO-TP single frame)
Response: 0x7E8  [len 41 <PID> A B ...]
```

Every supported PID reduces to `value = raw × scale + offset` with `raw = A` or
`A·256+B` — the table in `CanDecoderConfig.h` carries the pre-reduced constants:

| PID | Metric | Formula | Table entry (bytes, scale, offset) |
|---|---|---|---|
| 0x0C | RPM | (256A+B)/4 | 2, 0.25, 0 |
| 0x0D | Speed km/h | A | 1, 1, 0 |
| 0x05 | Coolant °C | A−40 | 1, 1, −40 |
| 0x04 | Load % | 100A/255 | 1, 0.3922, 0 |
| 0x42 | **Battery/module V** | (256A+B)/1000 | 2, 0.001, 0 |
| 0x5B | **Hybrid pack SOC %** | 100A/255 | 1, 0.3922, 0 |

Scheduling: each PID has its own period (RPM at 50 ms, fuel level at 5 s); the poll
task keeps **one request in flight at a time** with ≥ 60 ms spacing — polite to slow
ECUs and gateway modules.

### 4.2 Strategy B: passive raw-frame decoding (`RAW_SIGNAL_TABLE`)

For everything the OBD port doesn't expose — **especially the electrical system**
(intelligent battery sensor, alternator load, headlight status) — the master decodes
periodic broadcast frames DBC-style. Each entry describes one signal:

```
{ can_id, extended, start_bit, bit_length, byte_order, is_signed, scale, offset, metric_id }
```

Bit extraction (implemented in `extractRaw()` / `decodeSignal()`):

- **Intel / little-endian** (`@1+` in DBC): assemble the 8 payload bytes into a 64-bit
  word with byte 0 least-significant; `raw = (word >> start_bit) & mask`.
- **Motorola / big-endian** (`@0+`): assemble with byte 0 most-significant; convert
  the DBC MSB start bit to a word offset: `msb = 8·(start/8) + (7 − start mod 8)`,
  then `raw = (word >> (64 − msb − length)) & mask`.
- Signed signals get two's-complement sign extension before scaling.

**Worked example** — IBS battery current, `0x35A`, Intel, start 16, length 16, signed,
scale 0.1 A: payload `[A0 2E  38 FF  64 19 00 00]` → bytes 2..3 little-endian =
`0xFF38` → signed = −200 → **−20.0 A** (discharging).

> ⚠️ The electrical entries shipped in `RAW_SIGNAL_TABLE` are *representative
> examples* in typical IBS/BCM style. Actual IDs, positions and scales differ per
> manufacturer — capture your own bus (see §7) or use a public DBC before trusting
> any electrical reading.

### 4.3 Where each electrical metric usually comes from

| Metric | Best source |
|---|---|
| Battery voltage `0x0142` | OBD PID 0x42 (always available) or IBS frame (more accurate, at the post) |
| Battery current/SOC/SOH/temp `0x1101–0x1104` | IBS on the battery negative post, broadcast on body CAN (often gatewayed from LIN) |
| Alternator V/A/load `0x1105–0x1107` | ECU load-management frames (COM/LIN alternators are gatewayed to CAN on most platforms) |
| 12 V rail `0x1108` | BCM/fuse-box status frame, or measure locally with a divider and publish |
| Total load `0x1109` | Compute on master: `batt_V × (alt_A − batt_A)` when both sources exist |
| Night flag | BCM light-status bit (preferred) or LDR fallback |

---

## 5. Firmware Architecture (reference implementation)

Four FreeRTOS tasks, deliberately split across the two cores so CAN timing never
fights the Wi-Fi stack:

| Task | Core | Prio | Job |
|---|---|---|---|
| `twaiRxTask` | 1 | 10 | Blocking `twai_receive`; OBD responses + raw table decode → `publishMetric()` |
| `obdPollTask` | 1 | 5 | Per-PID scheduler, single outstanding request |
| `broadcastTask` | 0 | 8 | 20 Hz: snapshot fresh metrics → flags → multi-frame burst → `esp_now_send` |
| `housekeepingTask` | 0 | 3 | Night detection (LDR hysteresis or CAN bit), uptime metric, TWAI bus-off recovery |

Shared state is a 64-slot metric store guarded by a spinlock; the broadcaster copies
under lock and does all flag math and radio work outside it. TWAI RX queue depth is 64
frames to ride out full-bus bursts at 500 kbit/s.

**Freshness:** a metric not refreshed within `METRIC_TTL_MS` (1 s) silently leaves the
broadcast; the slave then marks it stale and renders `--`. Validity is thus end-to-end:
sensor → master TTL → `VALID` flag → slave stale timer.

---

## 6. Configuration Walkthrough (`CanDecoderConfig.h`)

Bring-up order for a new vehicle:

1. **Wire + listen:** `OBD_POLLING_ENABLED 0`, flash, open serial monitor. The 5 s
   stats line must show `CAN rx` climbing. If zero: swap CTX/CRX, check bitrate.
2. **Enable OBD:** set `OBD_POLLING_ENABLED 1` (on the OBD port only). Watch
   `OBD resp` climb and metrics appear on a slave's diagnostics screen.
3. **Map raw signals:** capture candump logs (§7), identify frames, fill
   `RAW_SIGNAL_TABLE` — start with the electrical system IBS frame.
4. **Set the safety floor:** adjust `THRESHOLD_TABLE` (per-metric warn/crit bounds,
   `NAN` disables a bound; low bounds catch undervoltage, high bounds overheat/overrev).
5. **Pick the night source:** `NIGHT_SOURCE_CAN` with a headlight bit, or
   `NIGHT_SOURCE_LDR` with the divider on GPIO 34.

---

## 7. Bench & Vehicle Test Plan

| # | Test | Method | Pass criterion |
|---|---|---|---|
| 1 | Contract sanity | Build both projects | `static_assert`s compile clean |
| 2 | Radio link | Master on bench, no CAN; slave diag screen | `Seq` climbing, `Drops 0`, ~20 pkt/s |
| 3 | Burst integrity | Add >28 fake `publishMetric` calls in a test task | Slave receives 2 frames/cycle, all metrics update, no drop growth |
| 4 | CAN decode | Second ESP32 as frame generator replaying candump logs | Metrics match the log values |
| 5 | OBD engine | ELM327-style bench simulator or the car, ignition on | `OBD resp` ≥ requests·0.95 |
| 6 | Alarm path | Force coolant > crit in simulator | Slave strobes overlay within 100 ms |
| 7 | Range/robustness | Master in engine bay, slave on dash, engine running | pps ≥ 18, drops < 1 % |
| 8 | Bus-off recovery | Short CANH-CANL for 2 s on the **bench** bus | Node logs recovery, resumes RX |

Capture tooling: any ESP32 running the RX task with frames printed, a USB-CAN adapter
with `candump -L`, or SavvyCAN for pattern-spotting (which bytes move with revs, with
lights, with load…).

---

## 8. Known Limits & Extension Points

- **Multi-frame ISO-TP responses** (VIN, DTCs, Service 22 on some ECUs) are not
  implemented — the poll engine is single-frame by design. Extend
  `handleObdResponse()` with flow-control (`0x30`) handling if you need Service 22.
- **29-bit OBD** (some trucks/US models): requests go to `0x18DB33F1`, responses from
  `0x18DAF1xx` — add an `extended` variant of `obdRequest()`.
- **Security:** ESP-NOW broadcasts are plaintext by protocol. The firehose carries no
  personal data, but if spoofing worries you, append a truncated HMAC to the frame
  tail and verify on the slave (bytes are available: 205 used of 250).
- **Second display / logger:** free — any listener on channel 1 sees the firehose.

---

## 9. Deliverable Map

| File | Role |
|---|---|
| [`platformio.ini`](platformio.ini) | Standalone PlatformIO project (ESP32 DevKit) |
| [`include/MasterPacket.h`](include/MasterPacket.h) | The contract — byte-identical twin of the slave's copy |
| [`include/CanDecoderConfig.h`](include/CanDecoderConfig.h) | **The only file you edit per vehicle** |
| [`src/main.cpp`](src/main.cpp) | Full reference implementation of everything above |

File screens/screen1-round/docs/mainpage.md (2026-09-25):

# Vehicle Telemetry System {#mainpage}

A two-node automotive telemetry system. A **master** node reads the vehicle's
CAN bus and broadcasts parsed engineering values over ESP-NOW; any number of
**slave** display nodes listen and render configurable gauges on a 1.28"
circular LCD.

@image latex none

## The two nodes

| | Master — "Data Firehose" | Slave — "Intelligent Canvas" |
|---|---|---|
| Hardware | ESP32 + SN65HVD230 CAN transceiver | ESP32-C3 all-in-one round display board |
| Knows the vehicle | **Yes** — CAN IDs, PIDs, scaling | Never |
| Knows the UI | Never | **Yes** — layout.json, gauges, watchdog |
| Radio | Broadcast-only transmitter | Receive-only listener |
| Source | `master/` | `screens/screen1-round/` |

The only coupling between them is @ref MasterPacket.h, a packed binary
contract that must stay byte-identical in both projects.

## Slave module map

The slave's `src/` tree is grouped by responsibility:

- @ref hal — hardware abstraction: panel, touch, button
  (@ref DisplayManager, @ref TouchManager, @ref ButtonManager)
- @ref telemetry — the radio link and the value cache
  (@ref NetworkManager, @ref TelemetryStore)
- @ref ui — the dynamic gauge engine (@ref UIBuilder)
- @ref config — persistence and the Gauge Studio web portal
  (@ref ConfigManager)

Every GPIO in the system is declared in exactly one place,
@ref HardwareConfig.h. No pin number appears anywhere else.

## Data flow

    Vehicle CAN ──► Master: parse to engineering units ──► ESP-NOW broadcast
                                                                │
                        ┌───────────────────────────────────────┘
                        ▼
    NetworkManager (Wi-Fi task) ──► TelemetryStore (EMA + lerp smoothing)
                                                                │
                                        UIBuilder (LVGL, 50 fps) ┘

`NetworkManager` runs its receive callback in the Wi-Fi task while `UIBuilder`
renders from the Arduino loop, so @ref TelemetryStore guards its slots with a
spinlock. That boundary is the only place in the slave where two execution
contexts meet.

## Two alarm paths — do not confuse them

1. **Per-gauge thresholds** (`thresholds` on a screen in `layout.json`) are
   cosmetic. They recolor and pulse one widget on one screen.
2. **The watchdog** (`watchdog.items`) is the safety guard. It polices a list
   of metrics whether or not any screen displays them, and raises a
   warning-triangle card over whichever screen is showing. See
   @ref UIBuilder::evalWatchdog.

Watchdog alarms are evaluated on **raw** values via
@ref TelemetryStore::peek, never on the smoothed display value — a guard must
react to what the sensor reported, not to a display filter that lags it.

## Where to start reading

- @ref MasterPacket.h — the wire contract, metric ID registry and flag bits
- @ref HardwareConfig.h — every pin and board constant
- `CanDecoderConfig.h` — the only file to edit when porting to a new vehicle
- `master/MASTER_NODE_BLUEPRINT.md` — full engineering rationale for the master
- `README.md` — build, flash and day-to-day operation

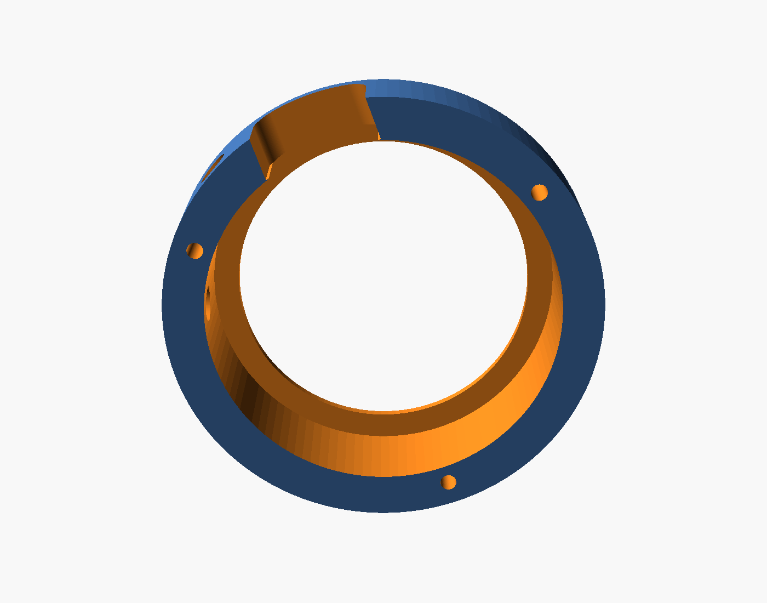
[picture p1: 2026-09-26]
screens/screen1-round/enclosure/preview/cup_back.png

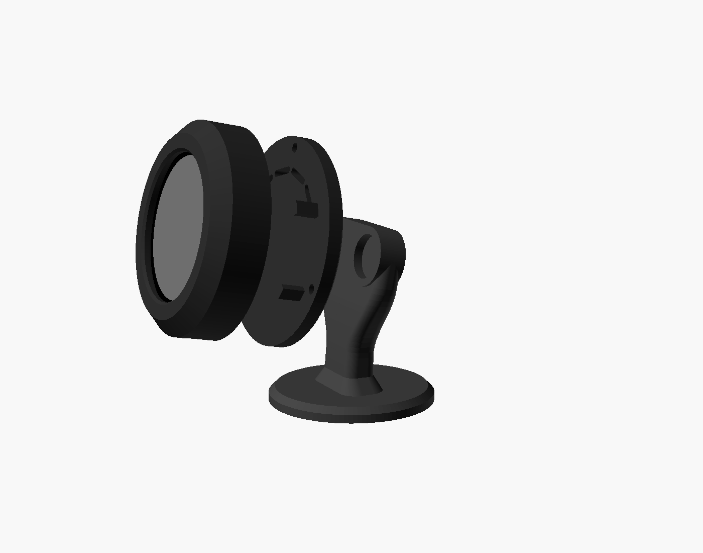
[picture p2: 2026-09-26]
screens/screen1-round/enclosure/preview/exploded.png

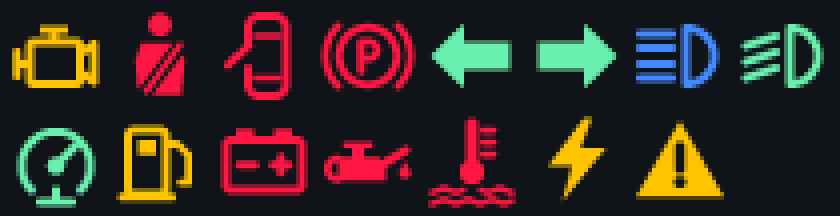
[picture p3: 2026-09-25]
screens/screen2-cluster/tools/telltale_preview.png

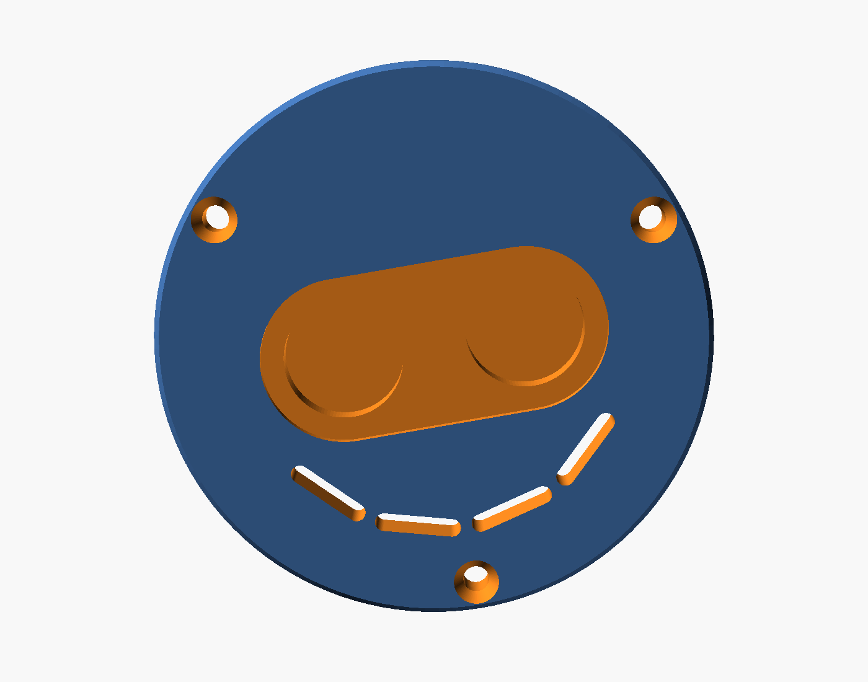
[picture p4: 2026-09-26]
screens/screen1-round/enclosure/preview/cover_back.png

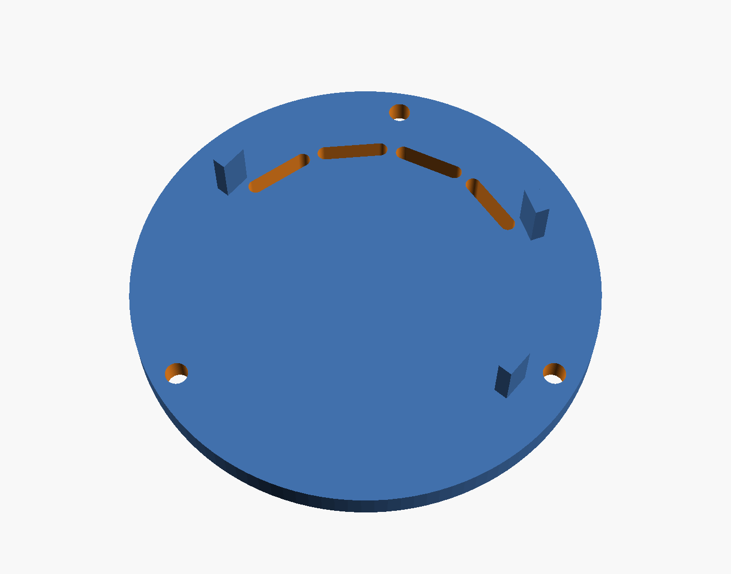
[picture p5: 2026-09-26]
screens/screen1-round/enclosure/preview/cover_front.png

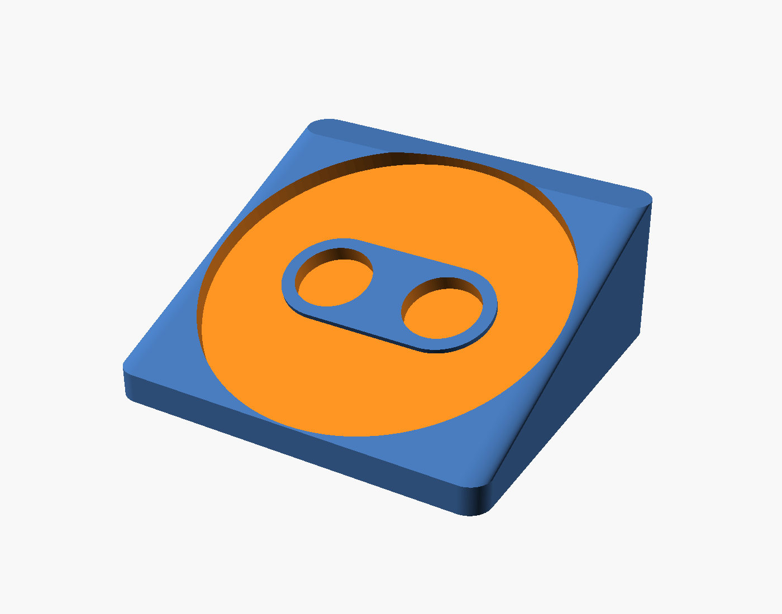
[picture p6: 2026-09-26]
screens/screen1-round/enclosure/preview/wedge.png

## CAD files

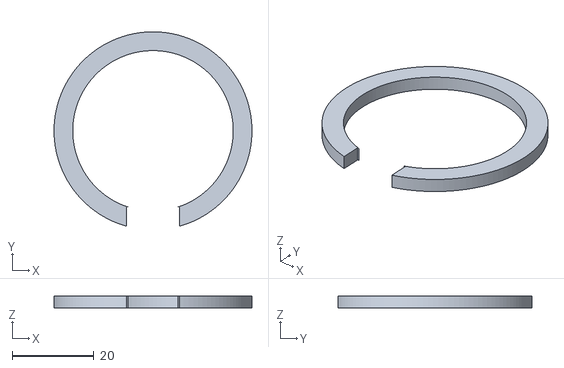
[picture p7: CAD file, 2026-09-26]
screens/screen1-round/enclosure/testring.stl
48.5 x 47.6 x 3.00

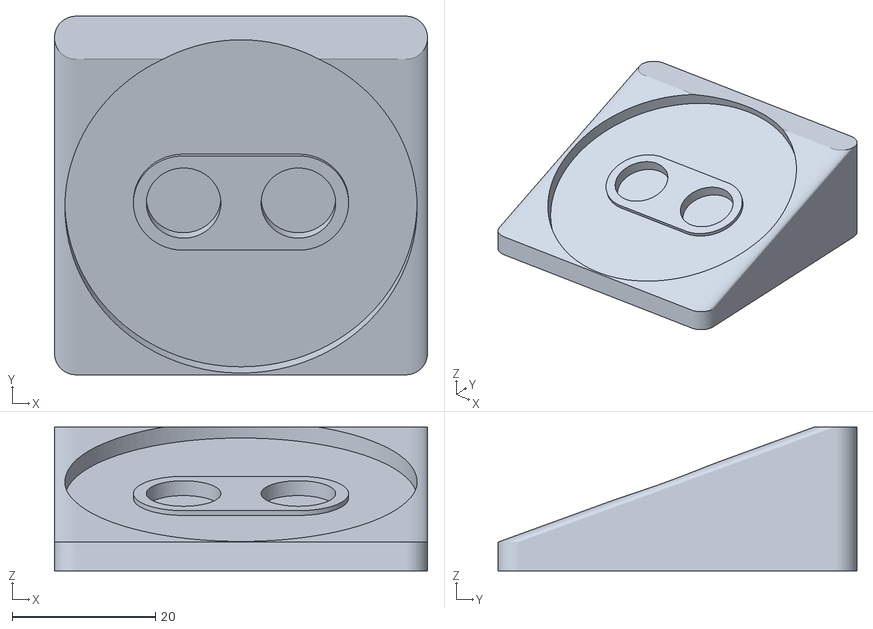
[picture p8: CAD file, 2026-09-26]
screens/screen1-round/enclosure/wedge.stl
52.0 x 50.0 x 20.0

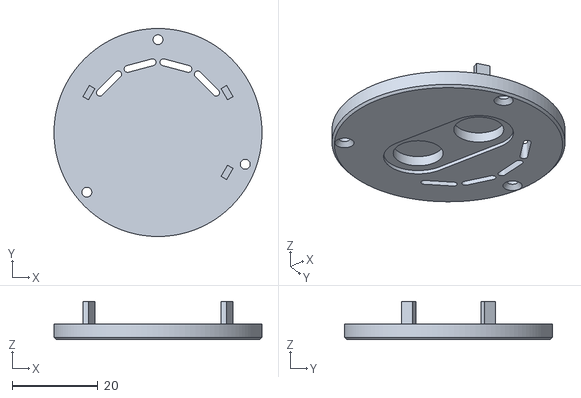
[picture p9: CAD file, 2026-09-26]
screens/screen1-round/enclosure/cover.stl
48.5 x 48.5 x 8.90

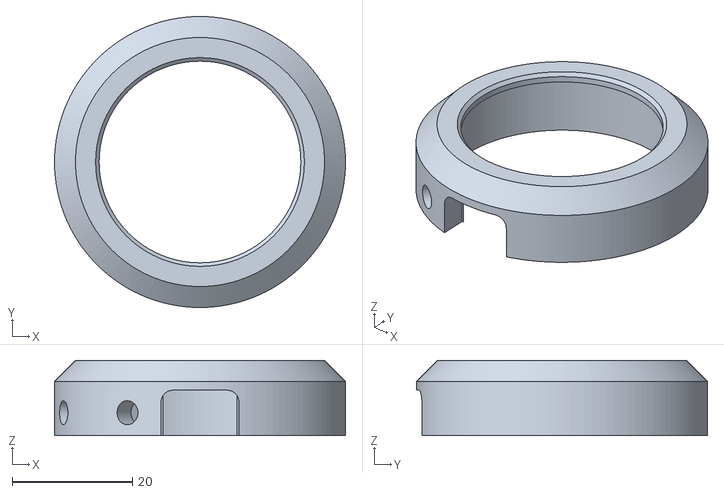
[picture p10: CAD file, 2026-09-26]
screens/screen1-round/enclosure/cup.stl
48.5 x 48.5 x 12.5

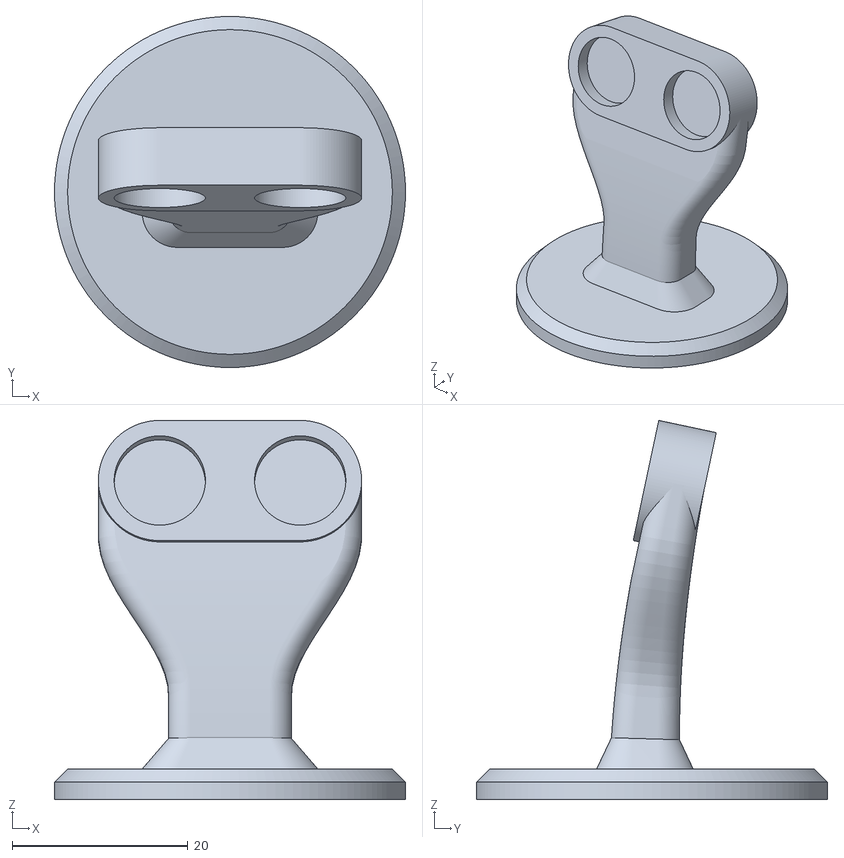
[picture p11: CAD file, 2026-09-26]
screens/screen1-round/enclosure/stand.stl
40.0 x 40.0 x 43.2

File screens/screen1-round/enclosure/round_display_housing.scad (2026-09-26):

// =============================================================================
//  Dash housing for the round display (screen 1)
//  ESP32-2424S012: ESP32-C3 + 1.28" 240x240 GC9A01 + CST816S touch, USB-C
// -----------------------------------------------------------------------------
//  A bevelled puck floating on a slim stalk, like a gauge pod. Parts:
//
//    cup     - the puck's body: one piece, a 45 degree bevel round the face, no
//              bezel ring and no screws on the front. The board goes in from
//              the BACK, glass first, against the front lip and a foam ring.
//              The USB-C plug leaves through a slot in the side wall, the two
//              side buttons through two holes.
//    cover   - the flat back: three posts press the board forward, three M2
//              countersunk screws into the wall, a shallow recess that the
//              stand's dock drops into, two magnet pockets and vents.
//    stand   - the mount: a round foot with a VHB pad pocket, a stalk that
//              rises and bends back to lie in the puck's plane, and a small
//              dock at its top with two magnets that holds the puck's back.
//              Nothing shows behind the puck. The USB-C plug hangs from the
//              puck's bottom with a right-angle lead going sideways.
//    wedge   - the alternative, lying down, for a dash you look down at.
//    testring- a 3 mm slice of the cavity with the USB slot: print it first
//              (a minute), drop the board in, adjust the numbers below.
//
//  Render one part:  openscad -o cup.stl -D 'part="cup"' round_display_housing.scad
//  Parts: "cup" "cover" "stand" "wedge" "testring"
//         "assembly" (the puck on the stand) "exploded" (the parts apart)
//
//  Everything in millimetres. Measure your board before printing (README).
// =============================================================================

part = "assembly";

/* ───────────── the board (measure these, defaults are the 2424S012) ───────── */
board_d      = 38.5;   // PCB diameter (the 38.5 of "38.5 x 37")
glass_d      = 36.0;   // cover glass outer diameter (sits on the PCB)
active_d     = 32.4;   // visible display area; the front lip must clear it
pcb_t        = 1.6;    // PCB thickness
front_stack  = 3.0;    // glass top above the PCB front face (LCD + touch glass)
back_stack   = 5.0;    // tallest thing on the back (JST battery socket, ESP module)

usb_angle    = 270;    // where the USB-C socket points (0 = right, 90 = up, 270 = down)
usb_w        = 13.0;   // slot width for the plug body (right-angle plug: ~12.5)
usb_h        = 7.5;    // slot height
usb_below    = 1.5;    // socket centre below the PCB back face

btn_angles   = [200, 240]; // side buttons (BOOT / RESET), degrees like usb_angle. [] = none
btn_d        = 4.0;    // finger-nail / paperclip hole
btn_below    = 1.5;    // switch plunger centre below the PCB back face

/* ───────────── printing and fit ─────────────────────────────────────────── */
clr_r        = 0.4;    // radial clearance around the PCB
clr_z        = 0.3;    // axial play
wall         = 4.6;    // cup wall (the cover screws bite into it)
cover_t      = 3.6;    // the back cover (dock recess + magnet pockets + floor)
lip_overlap  = 1.2;    // front lip over the glass edge
lip_t        = 1.6;    // front lip thickness
gasket_t     = 1.0;    // foam ring between lip and glass (takes up tolerance)
bevel        = 3.5;    // 45 deg bevel round the front edge: the lens look
post_angles  = [30, 150, 330]; // cover posts that press on the PCB edge (clear of USB and buttons)
post_w       = 3.0;    // post width along the wall
post_in      = 1.5;    // post reach into the cavity (under the PCB edge only)
screw_angles = [90, 220, 340]; // cover screws, M2 x 8 countersunk self-tapping, from the back.
                       // Unevenly spaced on purpose: the cover only fits one way round, so the
                       // dock recess is level when the USB slot is at the bottom
screw_hole   = 1.8;    // pilot hole in the cup wall
screw_head_d = 4.0;    // countersink in the cover
vent_angles  = [45, 75, 105, 135]; // vent slots in the cover, upper half (the stalk covers the lower)
magnet_d     = 10.0;   // two Ø10 x 2 mm disc magnets in cover and dock (0 = none)
magnet_t     = 2.0;
magnet_gap   = 16.0;   // centre-to-centre

/* ───────────── the stand (upright, on the dash top) ─────────────────────── */
face_tilt    = 12;     // the puck leans back from vertical by this much
plug_gap     = 9;      // clear height under the puck's bottom edge: a right-angle USB-C plug
stem_w       = 14;     // the stalk's section at the foot ...
stem_d       = 8;
stem_d_top   = 6;      // ... and its depth where it meets the dock (the dock is as deep)
stem_run     = 18;     // the straight run in the puck's plane before the dock
dock_h       = 14;     // the dock: a stadium magnet_gap + dock_h wide, dock_h tall
dock_t       = stem_d_top; // behind the puck's back plane, flush with the stalk ...
dock_boss    = 0.7;    // ... and this much into the cover's recess (locates the puck)
dock_clr     = 0.2;    // recess clearance round the boss
foot_d       = 40;     // round foot (a Ø34 VHB disc fits underneath)
foot_t       = 3.5;

/* ───────────── the wedge (alternative, lying down) ──────────────────────── */
tilt_deg     = 20;     // face tilts up towards the driver by this much
base_w       = 52;     // footprint (a 50 x 50 VHB pad fits underneath)
base_l       = 50;
base_min_t   = 4;      // thinnest edge of the wedge
recess_depth = 1.5;    // locating recess for the cup on top of the wedge

/* ───────────── derived ──────────────────────────────────────────────────── */
$fn = 120;
cav_d   = board_d + 2 * clr_r;                     // cavity diameter
outer_d = cav_d + 2 * wall;                        // puck diameter
z_pcb   = cover_t + clr_z + back_stack;            // PCB back face, from the puck's back
cup_h   = z_pcb + pcb_t + front_stack + gasket_t + lip_t;   // puck thickness
lip_in  = glass_d - 2 * lip_overlap;               // the opening
r_screw = cav_d / 2 + 2.0;                         // screw circle, in the wall
dock_w  = magnet_gap + dock_h;                     // the magnets sit in the stadium's round ends
eps = 0.01;

assert(lip_in >= active_d + 0.6, "the front lip would cover the display: reduce lip_overlap");
assert(r_screw - screw_hole / 2 - cav_d / 2 >= 1.0, "cover screws too close to the cavity");
assert(outer_d / 2 - r_screw - screw_head_d / 2 >= 0.4, "countersinks break out of the cover's edge");
assert(cover_t - dock_boss - 0.1 - magnet_t - 0.2 >= 0.6, "cover too thin for recess plus magnet pockets");
assert(dock_h >= magnet_d + 0.4 + 3, "dock too small round the magnets");
assert(dock_t + dock_boss - magnet_t - 0.2 >= 1.0, "dock too thin for the magnet pockets");

// The stand: the puck's centre sits here, so its bottom edge is plug_gap above the foot.
z_c = foot_t + plug_gap + (outer_d / 2) * cos(face_tilt);
/** The puck's frame on the stand: local z points at the driver (world -y, a
 *  little up), local y is up (leaning back by face_tilt). The cup's own z
 *  axis is this local z, so cup() and cover() drop straight in. */
module puck_frame() { translate([0, 0, z_c]) rotate([90 - face_tilt, 0, 0]) children(); }
/** A point of the puck frame in world coordinates. */
function pf(x, y, z) = [x, y * sin(face_tilt) - z * cos(face_tilt),
                        z_c + y * cos(face_tilt) + z * sin(face_tilt)];

/* ───────────── helpers ──────────────────────────────────────────────────── */
// A rounded slot through the cup wall at an angle: w wide, h tall, centred at
// height z. open_back runs it out through the cup's back, so the cover closes
// it and, printed front-down, there is nothing to bridge.
module wall_slot(ang, w, h, z, open_back = false) {
    r = min(2, h / 2 - 0.1);
    rotate([0, 0, ang])
        translate([cav_d / 2 - 1, 0, z])
            rotate([0, 90, 0])
                linear_extrude(wall + 2)
                    hull() {
                        offset(r = r) square([h - 2 * r, w - 2 * r], center = true);
                        if (open_back)
                            translate([h + 2, 0]) offset(r = r) square([h - 2 * r, w - 2 * r], center = true);
                    }
}
module round_hole(ang, d, z) {
    rotate([0, 0, ang])
        translate([cav_d / 2 - 1, 0, z])
            rotate([0, 90, 0])
                linear_extrude(wall + 2) circle(d = d);
}
module magnet_pockets(z0, depth) {
    if (magnet_d > 0)
        for (s = [-1, 1])
            translate([s * magnet_gap / 2, 0, z0])
                cylinder(d = magnet_d + 0.4, h = depth + eps);
}
module rounded_rect(w, l, r) { offset(r = r) offset(delta = -r) square([w, l], center = true); }
module stadium(w, h) { hull() for (s = [-1, 1]) translate([s * (w - h) / 2, 0]) circle(d = h); }
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

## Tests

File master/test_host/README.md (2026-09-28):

# Host test harness

Runs the **unmodified master firmware** (`src/main.cpp`, `Ssm2.cpp`, `Learner.cpp`,
`MasterConfig.cpp`) on the PC, inside a simulated car, with undefined-behaviour
trapping and bounds-checked containers.

```
python test_host/run.py                # build + every scenario (about 30 s)
python test_host/run.py auto guard     # just these
python test_host/run.py auto -v        # one scenario with the full firmware log
SIM_SEED=5 python test_host/run.py     # a differently shaped drive
python test_host/run.py portal_teach   # just the portal's teach-by-doing analysis (Node, no build)
```

A full run ends with `portal_teach`: `portal_tests.js` runs, in Node.js, the
portal page's own teach-by-doing analysis (every block of
`tools/portal_page.html` marked `teach-core`) on made-up traffic - a flashing
turn signal polled at any rate, a steady switch, a counter, a gear lever in
one field or spread over separate bits. Node is needed on the PATH, like g++.

Needs `g++` (WinLibs GCC: `winget install BrechtSanders.WinLibs.POSIX.UCRT`) and a
`pio run` done once (for ArduinoJson in `.pio/libdeps`). Debug a failure with
`gdb --args test_host/build/sim.exe <scenario>`.

`device_config` replays every settings file read off the car (`fixtures/`, one
run each, shown as `device_config[<file>]`); `DEVICE_CONFIG=path` replays
another one instead. The P1718 scenarios drive with the first fixture.

| Part | What it is |
| --- | --- |
| `mocks/` | Arduino, FreeRTOS, TWAI, LittleFS, Wi-Fi/ESP-NOW headers, same API as ESP-IDF 4.4 |
| `sim/sim_rtos.cpp` | Deterministic scheduler: one task runs at a time, virtual time jumps to the next wake-up, so a 4-minute drive takes ~2 s and every run is reproducible. It aborts on deadlock, on a task that spins without blocking, and on blocking inside a critical section |
| `sim/sim_bus.cpp` | TWAI controller (modes, error counters that wind down on good frames, bus-off, alerts), the car's broadcast frames, an engine ECU speaking OBD-II and SSM2 over real ISO-TP, a transmission ECU that answers 0x7DF and watches the engine ECU's broadcasts (it sets P1718 when they thin out), fault injection including a marginal link on which a normal-mode master error-flags - destroys - those broadcasts |
| `sim/sim_platform.cpp` | FreeRTOS queues and semaphores (flags mutex misuse), in-memory LittleFS (short writes, rename quirks), ESP-NOW decoded as a display would |
| `tests/scenarios.cpp` | The scenarios and their checks |
| `portal_tests.js` | The portal's teach-by-doing analysis, run in Node (`portal_teach`) |

What it cannot show: preemption in the middle of code that never blocks,
real electrical bus behaviour, and radio timing. Those need the car.

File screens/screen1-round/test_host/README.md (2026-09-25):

# Display test harness

Runs the display's **real UI code** — `src/ui` (UIBuilder, Telltales),
`src/telemetry/TelemetryStore.cpp` and `src/config/ConfigManager.cpp` — on the
PC, on the real LVGL from `.pio/libdeps`, drawing into a framebuffer, with a
simulated master broadcasting telemetry. Identical in both display projects.

```
python test_host/run.py                   # build + every scenario (a few seconds)
python test_host/run.py lamp_seatbelt     # just these
python test_host/run.py lamp_mil_once -v  # one scenario with the full firmware log
```

Needs `g++` (WinLibs GCC: `winget install BrechtSanders.WinLibs.POSIX.UCRT`) and
one `pio run` beforehand (for LVGL and ArduinoJson). Screenshots of every screen,
the dash, the lamp strip and the alert cards land in `test_host/shots/`.
Debug a crash with `gdb --args test_host/build/ui.exe <scenario>`.

| Part | What it is |
| --- | --- |
| `mocks/` | Arduino (String, millis), LittleFS in memory with short-write and no-overwrite-rename faults, WebServer (handlers called directly), Wi-Fi, the HAL singletons |
| `host/lvgl_host.cpp` | Framebuffer display, PNG writer, the simulated master, virtual time |
| `host/lv_budget.cpp` | What the LVGL heap would hold **on the ESP32** — see below |
| `tests/ui_tests.cpp` | The scenarios |

## LVGL heap on the device

LVGL's heap is a fixed pool (`LV_MEM_SIZE` in `include/lv_conf.h`), and running
out of it is not an error LVGL reports: the next widget comes back null and the
display reboots. The PC build has 8-byte pointers, so its own heap figures
overstate the device's by about half. The harness therefore walks every live
LVGL object and adds up the blocks it owns using the **32-bit** struct sizes
(`host/lv_sizes.c`, compiled with `-m32`), rounded the way LVGL's TLSF allocator
rounds on the ESP32. `boot_all_screens` prints the estimate per screen and fails
when less than 8 KB would be left. The firmware also logs the real figure at
boot, and the studio's System tab shows it.

What it cannot show: real touch, real panel timing, and the radio. Those need
the car.

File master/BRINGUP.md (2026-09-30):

# Master node bring-up — 2009 Subaru Legacy B4

Work through this in order. Each step proves one thing, so when something
fails you know which thing it was.

## 0. Before the car

Flash it on the bench first and confirm the serial console comes up:

```
pio run -t upload
pio device monitor
```

Every 5 s you should get a heartbeat, a diagnostics line and a bus census:

```
[stats] CAN rx: 0 | OBD resp: 0 | SSM2: 0 ok/0 err (0/s, 40 addr) | ESP-NOW tx: 100 (fail 0) | night: 0 | heap: ...
[diag ] mode AUTO | SSM2 idle | OBD-II idle
[bus ] no CAN frames yet - check CANH/CANL, bitrate, and that the ignition is on
```

`ESP-NOW tx` climbing with no CAN attached is correct and expected — the
broadcaster runs regardless, it just has nothing to say yet.

**Write down the MAC** printed at boot (it is the AP interface's MAC, which
is what the displays see):

```
ESP-NOW broadcasting on channel 1 via AP, this master is 9A:A3:16:EB:F9:34
```

Paste it into each display's Settings → `network.master_mac` if you want them
to ignore everything else on the channel. Optional, but it stops a second CAN
project injecting into your gauges. With its Wi-Fi switched off at boot
(Advanced → *Start this Wi-Fi at boot*) the master sends from its station MAC
instead - the boot line says which - so set the filter again after changing
that, or leave it empty.

## 1. Plug in — it configures itself

The diagnostic mode ships as **Automatic**. With the ignition on:

1. The census fills — wiring and bitrate are right. For the first 10 s the
   master only listens while the car's modules start up; the diagnostics
   line says `bus settling, requests in N s`. (Settings → *Wait after
   power-on*; 0 = no wait.)
2. The master sends the SSM2 init command. The ECU answers with its ROM ID
   and a bitmap of every parameter it supports; the master enables exactly
   those and never asks for the rest. Watch for:
   ```
   SSM2: ECU answered - SYS A21007 ROM 4B12785206, 96 capability bytes, 58 of 69 seeded parameters supported
   ```
3. Exchanges run back to back. The values a needle follows (RPM, MAP,
   throttle, timing, knock, A/F) go in every request; temperatures and
   voltages rotate through the remaining slots. Expect 20-40 exchanges/s.
4. If the ECU never answers SSM2, the master falls back to OBD-II by itself,
   asks which PIDs the ECU supports, and polls only those.

Open the portal (`Telemetry-Master-Config`, 192.168.4.1). The **Live** tab
says which engine is talking, the ECU ID, and how many parameters this ECU
supports; the **Subaru SSM** tab marks each parameter ✓ or ✗ from the ECU's
own answer.

| What you see | What it means |
|---|---|
| IDs appear in the census | Wiring and bitrate are right. |
| Nothing, ever | CANH/CANL swapped or not connected, termination jumper still fitted, transceiver not powered, or RS not grounded. |
| Bus alive, `SSM2 no answer`, `OBD-II active` | This ECU does not speak SSM2 over CAN (K-line only). OBD-II data flows; the Subaru extras are unavailable on this port. |
| Bus alive, neither answers | Wrong bus (a body CAN rather than the OBD port) or the ignition is off. |
| `SSM2: negative response … code 0x..` | The ECU refused a request. Usually one address it does not have; the parameter list will settle after the init. |
| Request size shrinking in the log | The ECU tolerates fewer addresses per request than the maximum; it settles by itself. Lower "Max addresses" in the portal if it keeps oscillating. |

## 2. Raw frames verify themselves

The **Signals** tab holds Subaru broadcast frames documented for the next
generation of this car. They start in **Auto**: decoded but not published.
Each decoded value is compared with the ECU's own figure (SSM2/OBD-II); after
30 agreeing samples across a wide enough range the signal becomes
**Verified** and starts publishing — at the frame's own rate, 50-100 Hz —
and the other Auto signals of the same frame (brake pedal alongside speed,
oil temperature alongside coolant) are verified with it. Disagreement marks
it **Rejected**.

Drive for a few minutes. Then look at the Signals tab: anything Verified is
now a confirmed fact about this car; anything Rejected was not this car's
layout. Nothing wrong can reach a gauge in between.

The headlight bit (0x152) is verified against the ECU's light-switch input,
which SSM2 already provides — so night mode works from the first drive with
no LDR and no extra wire, and the CAN bit is only a faster copy of it.

## 3. Finding more

With the census in front of you, park the car and change one thing at a
time — headlights on, brake pressed, gear selected — and watch which ID's
payload moves. Add a signal, give it a **Ref** metric if the ECU reports the
same quantity, and set it to Auto; the verifier does the rest.

**Teach by doing** (Bus tab) does the watching for you:

- **On / off** — switches: lights, doors, handbrake, fog lights, VDC off.
  Turn signals and hazards too: leave the lamp flashing through the ON step.
  The master counts every flip of every bit, frame by frame, so a bit that
  flashes only while the lever is on is found as the flasher (the portal
  says how many times it flashed); the screens follow the car's own flash.
- **Positions** — the gear lever (pick *Gear lever*), SI-Drive, anything
  with a handful of set positions. Foot on the brake the whole time, then
  move it through the positions in the order listed (P R N D P by default -
  ending back in P checks every bit twice; add M, or 3 2 1, if the lever has
  them) and hold each until the next is asked for. The lever is learnt as
  one value from the combination of every bit that changes with it - bits
  side by side or scattered through a byte, in one byte or several - and
  saved with a table of what each pattern means. Bits beside them that do
  something else are left out, so they can change later without upsetting
  the lever. Only when no single frame tells every position apart (reverse
  from one module, park from another) does it offer one on/off value per
  position instead: *Lever in P*, *Reverse*, *Lever in N*, *Lever in D* - the
  master puts those together as the gear lever. Either way the screens'
  gear shows P R N D (or the gear itself in the manual gate).
- **A moving value** — steering angle, wheel speeds, brake pressure.

Doors taught one at a time (*Door FL* … *Trunk open*, *Hood open*) light
the screens' door lamp through *Door open*, which the master sets whenever
any of them is open - unless *Door open* itself has been taught.

## Sleep

The master deep-sleeps after 90 s of bus silence and wakes on the first CAN
frame. It stays awake while a portal client is connected, but only for a few
minutes, so a phone that remembers the AP cannot keep it awake in the
garage. The dev board's regulator and USB bridge still draw in sleep; the
chip itself is microamps.

## Safety notes

- OBD pin 16 is **permanently live**. Without the sleep logic this draws
  100-200 mA and flattens the battery over a few weeks parked.
- Fuse the 12 V tap and use an automotive-rated buck; vehicle rails see
  load-dump transients well above 12 V.
- Keep the CANH/CANL stub under ~30 cm and twisted.
- Never fit the transceiver's 120 ohm termination on a vehicle bus.
- Fit a 10 kΩ pull-up from the transceiver's TXD to 3V3. While the ESP32 is in
  reset (a brown-out at cranking, say) its pins float; a TXD left low drives
  the bus dominant and jams every module. The firmware drives TXD recessive
  the moment it starts and latches it across sleep, but only the resistor
  covers the reset window itself.
- If the car sets P1718/P0700 (transmission ECU losing the engine ECU's CAN
  messages): `P1718_DIAGNOSIS.md` has the causes, the fixes, and a test plan.
  The portal's Diagnostics tab keeps the evidence (reset reasons, guard trips).
- **Silent** mode (CAN tab) makes the controller electrically incapable of
  transmitting, for first contact with an unfamiliar bus.
- The portal is the only way into the settings (there is no serial console,
  and they survive a reflash). Switched its Wi-Fi off at boot? Hold the
  board's **BOOT** button for 3 seconds while the master runs (ignition on):
  it switches the Wi-Fi back on and restarts. A Wi-Fi name or password the
  access point cannot use is refused when saved, and should the AP still not
  start, it comes up as `Telemetry-Master-Config`, open.

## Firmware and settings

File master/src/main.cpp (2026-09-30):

/**
 * @file main.cpp
 * @ingroup master
 * @brief CAN Telemetry Bridge — MASTER NODE reference implementation.
 *
 * Architecture (FreeRTOS, ESP32-S3):
 *
 *   ┌─────────────┐   twai_receive   ┌──────────────┐  publishMetric  ┌──────────────┐
 *   │ Vehicle CAN │ ───────────────► │ twaiRxTask   │ ──────────────► │ Metric store │
 *   │  (TWAI +    │                  │ · OBD resp   │                 │ (192 slots,  │
 *   │ SN65HVD230) │ ◄─────────────── │ · RAW table  │                 │  spinlock,   │
 *   └─────────────┘  twai_transmit   │ · verifier   │                 │  per-source  │
 *          ▲                         └──────────────┘                 │  priority)   │
 *          │                                                          └──────┬───────┘
 *   ┌──────┴───────┐  ┌──────────────┐                     ┌────────────────▼──────────┐
 *   │ obdPollTask  │  │ ssm2Task     │  one dialogue       │ broadcastTask (25 Hz)     │
 *   │ 0x7DF PIDs   │  │ 0x7E0 ISO-TP │  at a time (mutex)  │ changed metrics + keep-   │
 *   └──────────────┘  └──────────────┘                     │ alives → ≤28/frame BURST  │
 *                                                          │ → ESP-NOW FF:…FF          │
 *                                                          └───────────────────────────┘
 *
 * The node has ZERO UI knowledge: it never knows what a slave renders.
 * Everything vehicle-specific is in include/CanDecoderConfig.h and the SSM2
 * seed table in MasterConfig.cpp. Full design rationale:
 * MASTER_NODE_BLUEPRINT.md (next to platformio.ini)
 */
#include <Arduino.h>
#include <esp_sleep.h>
#include <esp_system.h>
#include <WiFi.h>
#include <esp_now.h>
#include <esp_wifi.h>
#include <freertos/semphr.h>
#include <algorithm>
#include <vector>
#include <LittleFS.h>
#include "driver/twai.h"
#include "driver/gpio.h"
#include "hal/twai_ll.h"
#include "esp_rom_gpio.h"
#include "soc/gpio_sig_map.h"

#include "MasterPacket.h"
#include "CanDecoderConfig.h"
#include "MasterConfig.h"
#include "MasterTelemetry.h"
#include "Learner.h"
#include "Ssm2.h"
#include "WebPortal.h"

/**
 * @defgroup master Master Node
 * @brief CAN acquisition and the ESP-NOW broadcaster.
 *
 * Vehicle-specific configuration lives entirely in
 * @ref CanDecoderConfig.h; nothing in this file needs editing to port the
 * bridge to another car.
 * @{
 */

/* ═══════════════════════════ metric store ════════════════════════════════ */

/** @brief Capacity of the master's metric store.
 *
 *  More than @ref TELEMETRY_MAX_METRICS on purpose: the broadcaster splits
 *  the store into multi-frame bursts, so the total channel count is not
 *  limited by the 250-byte ESP-NOW frame.
 */
static constexpr size_t MAX_MASTER_METRICS = 192;

/** A value from a higher-ranked source blocks lower-ranked writers for this
 *  long. Long enough to cover one poll period of the faster source, short
 *  enough that a source going away hands over within half a second. */
/* The hold time is Cfg.sourceHoldMs - editable in the portal. */

/** @brief One parsed channel awaiting broadcast. */
struct MasterMetric {
    uint16_t id;            /**< Metric ID — see @ref MetricIDs.        */
    float    value;         /**< Latest engineering-unit value.         */
    uint32_t lastUpdateMs;  /**< millis() of the last update, for TTL.  */
    uint8_t  source;        /**< @ref MetricSource of the last write.   */
    bool     used;          /**< Slot has been claimed.                 */
    float    sentValue;     /**< Value in the last broadcast.           */
    uint32_t sentMs;        /**< millis() of the last broadcast.        */
    bool     everSent;      /**< At least one broadcast has carried it. */
};

/** @brief The metric store, shared between the CAN and broadcast tasks. */
static MasterMetric s_metrics[MAX_MASTER_METRICS] = {};
/** @brief Guards @ref s_metrics across the task boundary. */
static portMUX_TYPE s_metricMux = portMUX_INITIALIZER_UNLOCKED;
/** @brief Latest night-mode decision, stamped onto every outgoing entry. */
static volatile bool s_night = false;

/** @name Counters for the 5 s serial heartbeat
 *  @{ */
static volatile uint32_t s_canFramesRx  = 0;  /**< CAN frames received.     */
static volatile uint32_t s_obdResponses = 0;  /**< OBD replies decoded.     */
static volatile uint32_t s_espnowFrames = 0;  /**< Broadcasts accepted.     */
static volatile uint32_t s_espnowFailed = 0;  /**< Broadcasts refused.      */
/**
 * Metric entries actually carried, which is the number that answers "is data
 * flowing". Frames alone are misleading once the broadcaster is change-driven:
 * a quiet bench with five unchanging housekeeping channels produces a handful
 * of keep-alive frames per second, while a running engine produces far more
 * than the old send-everything-every-burst scheme ever did. Counting payload
 * makes that visible instead of alarming.
 */
static volatile uint32_t s_espnowMetrics = 0;
/** millis() of the last CAN frame. Zero means none since boot. */
static volatile uint32_t s_lastCanMs = 0;
/** millis() when the bus last came up: its first frame since boot, or after
 *  BUS_QUIET_MS without one. The settle wait counts from here. */
static volatile uint32_t s_busUpMs = 0;
static volatile uint32_t s_busSession = 0;      /**< Times it came up (0 = never). */
static volatile uint32_t s_settledSession = 0;  /**< The one whose wait is over, */
static volatile uint32_t s_settledAtMs = 0;     /**< ...and since when.          */
/** @} */

/* ═══════════════════════════ evidence log ════════════════════════════════
 *
 * A small persistent record of what the master was doing when the bus misbehaved,
 * so one drive can say which fault it is instead of a shrug. Boot and reset
 * reasons (a brownout at cranking looks nothing like a clean power-on), the bus
 * coming up and settling, every guard trip with the error counters and what we
 * were transmitting at the time, bus-off, and sleep. Kept in a ring on LittleFS
 * (its own file, so it survives a firmware update alongside the config) and shown
 * in the portal's Diagnostics tab.
 *
 * Writing is split in two: evLog() only appends to the RAM ring under a spinlock
 * (safe from any task, no I/O), and loop() flushes the ring to flash when it is
 * dirty - so the CAN receive path never touches the filesystem.
 */
enum EvType : uint8_t {
    EV_BOOT = 0,     /**< a = esp_reset_reason(), b = cfg version.            */
    EV_BUS_UP,       /**< the bus produced its first frame (a = session).     */
    EV_SETTLE_END,   /**< the settle wait ended; requests allowed.            */
    EV_TX_TRIP,      /**< bus guard: errors during our own frames (a = count).*/
    EV_RX_TRIP,      /**< receive-error guard: we were corrupting frames (a=REC).*/
    EV_BUS_OFF,      /**< the controller went bus-off.                        */
    EV_SLEEP,        /**< entering deep sleep.                                */
    EV_RESUME,       /**< the guard was cleared from the portal.              */
    EV_TYPE_COUNT
};

/** What the master was transmitting when an event happened, as a bitmask, so a
 *  burst can be pinned to what provoked it. */
static uint8_t diagActivityMask();

struct EvRecord {
    uint32_t ms;    /**< millis() when it happened.                 */
    uint8_t  type;  /**< @ref EvType.                               */
    uint8_t  act;   /**< diagActivityMask() at the time.            */
    uint16_t a;     /**< Type-specific (reset reason, error count). */
    uint16_t b;     /**< Type-specific.                             */
};

static constexpr size_t EV_MAX = 48;
static EvRecord s_ev[EV_MAX] = {};
static volatile uint8_t s_evHead = 0;    /**< Next write slot.        */
static volatile uint8_t s_evCount = 0;   /**< Records held (<= EV_MAX).*/
static portMUX_TYPE s_evMux = portMUX_INITIALIZER_UNLOCKED;
static volatile bool s_evDirty = false;
/** One writer of the file at a time: loop() flushes it, and the sleep path
 *  flushes it from the housekeeping task. */
static SemaphoreHandle_t s_evSaveMutex = nullptr;
static constexpr const char *EV_PATH = "/evlog.json";
static constexpr const char *EV_TMP  = "/evlog.tmp";

/** Append one event to the RAM ring. No I/O: loop() writes it to flash. */
static void evLog(uint8_t type, uint16_t a = 0, uint16_t b = 0) {
    const uint32_t now = millis();
    const uint8_t act = diagActivityMask();
    portENTER_CRITICAL(&s_evMux);
    EvRecord &r = s_ev[s_evHead];
    r.ms = now; r.type = type; r.act = act; r.a = a; r.b = b;
    s_evHead = (uint8_t)((s_evHead + 1) % EV_MAX);
    if (s_evCount < EV_MAX) s_evCount++;
    s_evDirty = true;
    portEXIT_CRITICAL(&s_evMux);
}

/** Load the ring from flash at boot, oldest first, so history survives a reset. */
static void evLoad() {
    File f = LittleFS.open(EV_PATH, "r");
    if (!f && LittleFS.exists(EV_TMP)) f = LittleFS.open(EV_TMP, "r");
    if (!f) return;
    JsonDocument d;
    const DeserializationError err = deserializeJson(d, f);
    f.close();
    if (err || !d.is<JsonArrayConst>()) return;
    for (JsonVariantConst v : d.as<JsonArrayConst>()) {
        if (!v.is<JsonArrayConst>()) continue;
        JsonArrayConst rec = v.as<JsonArrayConst>();
        if (rec.size() < 5) continue;
        EvRecord &r = s_ev[s_evHead];
        r.ms   = rec[0] | 0u;
        r.type = (uint8_t)(rec[1] | 0);
        r.act  = (uint8_t)(rec[2] | 0);
        r.a    = (uint16_t)(rec[3] | 0);
        r.b    = (uint16_t)(rec[4] | 0);
        s_evHead = (uint8_t)((s_evHead + 1) % EV_MAX);
        if (s_evCount < EV_MAX) s_evCount++;
    }
}

/** Copy the ring oldest-first into @p out. */
static size_t evSnapshot(EvRecord *out, size_t max) {
    portENTER_CRITICAL(&s_evMux);
    const uint8_t n = s_evCount;
    const uint8_t start = (uint8_t)((s_evHead + EV_MAX - n) % EV_MAX);
    size_t w = 0;
    for (uint8_t i = 0; i < n && w < max; i++)
        out[w++] = s_ev[(start + i) % EV_MAX];
    portEXIT_CRITICAL(&s_evMux);
    return w;
}

/** Flush the ring to flash (atomic tmp+rename, like the config). */
static void evSaveNow() {
    if (!s_evSaveMutex) return;
    xSemaphoreTake(s_evSaveMutex, portMAX_DELAY);
    static EvRecord snap[EV_MAX];
    const size_t n = evSnapshot(snap, EV_MAX);
    JsonDocument d;
    JsonArray arr = d.to<JsonArray>();
    for (size_t i = 0; i < n; i++) {
        JsonArray r = arr.add<JsonArray>();
        r.add(snap[i].ms); r.add(snap[i].type); r.add(snap[i].act);
        r.add(snap[i].a);  r.add(snap[i].b);
    }
    masterBusStall();                            // the flash write holds the CAN interrupt off
    File f = LittleFS.open(EV_TMP, "w");
    if (f) {
        const size_t expected = measureJson(d);
        const size_t written = serializeJson(d, f);
        f.close();
        if (!written || written != expected) {
            LittleFS.remove(EV_TMP);              // a short write never replaces the log
        } else if (!LittleFS.rename(EV_TMP, EV_PATH)) {
            LittleFS.remove(EV_PATH);
            LittleFS.rename(EV_TMP, EV_PATH);
        }
    }
    xSemaphoreGive(s_evSaveMutex);
}

/** Called from loop(): write the ring to flash when it changed, at most every
 *  few seconds so a run of events is not a run of flash writes. */
static void evService() {
    static uint32_t lastSave = 0;
    if (!s_evDirty) return;
    if (lastSave && millis() - lastSave < 3000) return;
    s_evDirty = false;
    lastSave = millis();
    evSaveNow();
}

/** Human-readable event names, shared by the serial log and the portal. */
static const char *evName(uint8_t type) {
    static const char *N[] = { "boot", "bus-up", "settled", "tx-guard-trip",
                               "rx-guard-trip", "bus-off", "sleep", "resume" };
    return type < EV_TYPE_COUNT ? N[type] : "?";
}

static MasterMetric *findSlot(uint16_t id) {
    for (auto &m : s_metrics)
        if (m.used && m.id == id) return &m;
    return nullptr;
}

void publishMetric(uint16_t id, float value, uint8_t source) {
    // A NaN would also defeat the broadcaster's change test (NaN != NaN) and
    // go out every burst.
    if (!isfinite(value)) return;
    const uint32_t now = millis();
    portENTER_CRITICAL(&s_metricMux);
    MasterMetric *slot = findSlot(id);
    if (!slot)
        for (auto &m : s_metrics)
            if (!m.used) { slot = &m; slot->used = true; slot->id = id;
                           slot->everSent = false; slot->source = SRC_NONE; break; }
    if (slot) {
        /*
         * Source priority. A raw broadcast frame at 50 Hz must not be
         * overwritten by the same quantity from a 5 Hz OBD poll a moment
         * later - the needle would jitter between two sample clocks. So a
         * lower-ranked writer yields while a higher-ranked one is fresh.
         */
        const bool blocked = slot->source > source &&
                             now - slot->lastUpdateMs < Cfg.sourceHoldMs;
        if (!blocked) {
            slot->value        = value;
            slot->source       = source;
            slot->lastUpdateMs = now;
        }
    }
    portEXIT_CRITICAL(&s_metricMux);
    // Every requested value is a reference the learner can match the bus
    // against - that is how requests teach the master to stop requesting.
    if (source == SRC_OBD || source == SRC_SSM) learnerOnRef(id, value);
}

bool metricLookup(uint16_t id, float &value, uint32_t &ageMs, uint8_t &source) {
    bool ok = false;
    portENTER_CRITICAL(&s_metricMux);
    const MasterMetric *m = findSlot(id);
    if (m) {
        value  = m->value;
        ageMs  = millis() - m->lastUpdateMs;
        source = m->source;
        ok = true;
    }
    portEXIT_CRITICAL(&s_metricMux);
    return ok;
}

bool metricCoveredAbove(uint16_t id, uint8_t below, uint32_t maxAgeMs) {
    bool covered = false;
    portENTER_CRITICAL(&s_metricMux);
    const MasterMetric *m = findSlot(id);
    if (m) covered = m->source > below && millis() - m->lastUpdateMs < maxAgeMs;
    portEXIT_CRITICAL(&s_metricMux);
    return covered;
}

/**
 * @brief Map a value onto its wire flags.
 * @param id Metric ID, used to find the row in @ref THRESHOLD_TABLE.
 * @param v  Value to classify.
 * @return @ref METRIC_FLAG_VALID plus any warning/critical/night bits. A NAN
 *         bound in the table disables that comparison.
 */
static uint8_t computeFlags(uint16_t id, float v) {
    uint8_t flags = METRIC_FLAG_VALID;
    for (auto &t : THRESHOLD_TABLE) {
        if (t.metric_id != id) continue;
        if ((!isnan(t.crit_low)  && v <= t.crit_low) ||
            (!isnan(t.crit_high) && v >= t.crit_high))
            flags |= METRIC_FLAG_CRITICAL;
        else if ((!isnan(t.warn_low)  && v <= t.warn_low) ||
                 (!isnan(t.warn_high) && v >= t.warn_high))
            flags |= METRIC_FLAG_WARNING;
        break;
    }
    if (s_night) flags |= METRIC_FLAG_NIGHT;
    return flags;
}

/* ═══════════════════════ diagnostics arbitration ═════════════════════════
 *
 * Both engines transmit to the ECU and both listen on 0x7E8. Left to
 * themselves they would interleave on the bus, and an OBD single-frame reply
 * landing in the middle of an SSM2 multi-frame exchange corrupts both. So a
 * mutex serialises dialogues, and the arbiter decides which engine runs at
 * all: in AUTO the order is listen, then OBD-II, then SSM2 (see
 * diagSsmWanted below). Each engine skips whatever a better-ranked source
 * already delivers, so no value is asked for twice.
 */
static SemaphoreHandle_t s_busMutex   = nullptr;
static volatile uint8_t  s_ssmAnswers = 0;   /**< 0 unknown, 1 yes, 2 no. */
static volatile uint8_t  s_obdAnswers = 0;
static volatile bool     s_obdActive  = false;

/** No frame for this long and the bus counts as down (car off, or wiring). */
static constexpr uint32_t BUS_QUIET_MS = 2000;

bool diagBusAlive() {
    const uint32_t last = s_lastCanMs;
    return last && millis() - last < BUS_QUIET_MS;
}

static volatile bool s_obdSettled = false;   /**< One full OBD pass done. */
bool diagObdSettled() { return s_obdSettled; }

/*
 * AUTO is "listen, then OBD-II, then SSM2". OBD-II always runs (it skips any
 * PID a broadcast frame already delivers). SSM2 starts only once OBD-II has
 * finished a full pass - so it can see what OBD-II covers and ask for the
 * rest - or once OBD-II has proved the ECU will not answer it at all.
 */
bool diagSsmWanted() {
    switch (Cfg.diagMode) {
        case DIAG_MODE_SSM: case DIAG_MODE_BOTH: return true;
        case DIAG_MODE_AUTO: return s_obdAnswers == 2 || s_obdSettled;
        default: return false;
    }
}

bool diagObdWanted() {
    switch (Cfg.diagMode) {
        case DIAG_MODE_OBD: case DIAG_MODE_BOTH: return true;
        case DIAG_MODE_AUTO: return true;
        default: return false;
    }
}

void diagReportSsm(bool answered) { s_ssmAnswers = answered ? 1 : 2; }
void diagReportObd(bool answered) { s_obdAnswers = answered ? 1 : 2; }
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
void loop() {
    static uint32_t last = 0;
    if (millis() - last >= 5000) {
        const uint32_t nowMs = millis();
        const float dt = last ? (nowMs - last) / 1000.0f : 0.0f;
        static uint32_t lastFrames = 0, lastMetrics = 0;
        const float fps = dt ? (s_espnowFrames  - lastFrames)  / dt : 0.0f;
        const float mps = dt ? (s_espnowMetrics - lastMetrics) / dt : 0.0f;
        lastFrames = s_espnowFrames; lastMetrics = s_espnowMetrics;
        last = nowMs;
        Ssm2Status ss;
        ssm2GetStatus(ss);
        /*
         * Frames AND metrics per second. The broadcaster only sends channels
         * whose value moved, so the frame rate is a function of how much the
         * car is doing, not of how healthy the link is - metrics/s is the one
         * to watch.
         */
        Serial.printf("[stats] CAN rx: %u | OBD resp: %u | SSM2: %u ok/%u err "
                      "(%.0f/s, %u addr) | ESP-NOW: %.0f frame/s, %.0f metric/s "
                      "(%u sent, %u fail) | night: %d | heap: %u\n",
                      s_canFramesRx, s_obdResponses, ss.responses, ss.errors,
                      ss.exchPerSec, ss.batch, fps, mps,
                      s_espnowFrames, s_espnowFailed,
                      (int)s_night, ESP.getFreeHeap());
        static const char *MODES[] = {"AUTO", "SSM2", "OBD-II", "BOTH", "SILENT"};
        char settleTxt[48] = "";
        const uint32_t settle = settleLeft();
        if (settle && diagBusAlive())
            snprintf(settleTxt, sizeof(settleTxt), " | bus settling, requests in %u s",
                     (unsigned)((settle + 999) / 1000));
        Serial.printf("[diag ] mode %s%s | SSM2 %s%s | OBD-II %s\n",
                      MODES[Cfg.diagMode > 4 ? 0 : Cfg.diagMode], settleTxt,
                      ss.active ? "active" : (s_ssmAnswers == 2 ? "no answer" : "idle"),
                      ss.initOk ? (String(", ECU ") + ss.ecuId + " (" + ss.supported +
                                   "/" + ss.total + " params)").c_str() : "",
                      s_obdActive ? "active" : (s_obdAnswers == 2 ? "no answer" : "idle"));
        censusPrint();
        {
            // What the controller says the errors are (see errKindAdd).
            ErrKindView ek[2];
            const size_t nk = masterErrorKinds(ek, 2);
            for (size_t i = 0; i < nk; i++) {
                char txt[64];
                errKindText(ek[i].code, txt, sizeof(txt));
                Serial.printf("[errs ] %s, %s: %u errors\n", txt,
                              ek[i].silent ? "listen-only" : "normal mode", (unsigned)ek[i].errors);
            }
            // Where they come from: frames missed per mode, and the radio.
            MasterStats ls;
            masterGetStats(ls);
            Serial.printf("[ctrl ] TEC %u REC %u | errors: %u during our frames, %u otherwise | "
                          "tx failed %u, arbitration lost %u | listen-only pin: TEC %u, "
                          "pinned again %u\n",
                          (unsigned)ls.tec, (unsigned)ls.rec, (unsigned)ls.errWhileTx,
                          (unsigned)ls.errIdle, (unsigned)ls.txFailed, (unsigned)ls.arbLost,
                          (unsigned)ls.lomTecRead, (unsigned)ls.lomRepins);
            if (ls.expected[0] || ls.expected[1] || ls.errRadioChecked)
                Serial.printf("[link ] missed %u of %u normal, %u of %u listen-only | "
                              "errors near the radio %u of %u (radio busy %u.%u%%)\n",
                              (unsigned)ls.missed[0], (unsigned)ls.expected[0],
                              (unsigned)ls.missed[1], (unsigned)ls.expected[1],
                              (unsigned)ls.errNearRadio, (unsigned)ls.errRadioChecked,
                              ls.radioHotPermille / 10, ls.radioHotPermille % 10);
        }
    }
    Portal.loop();
    if (Cfg.radioDbm != s_radioDbmApplied) applyRadioPower();
    Cfg.serviceSave();
    evService();
    portalRescueCheck();
    delay(10);
}

/** @} */  // end of master group

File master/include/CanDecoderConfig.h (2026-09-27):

/**
 * @file CanDecoderConfig.h
 * @brief THE vehicle-adaptation file of the Master Node. Everything that is
 *        car-specific lives here: GPIO wiring, bus speed, which OBD-II PIDs
 *        to poll, which raw CAN frames to sniff-decode (DBC-style), alarm
 *        thresholds, and the night-mode source.
 *
 * The main.cpp engine is generic — porting the Master to a new vehicle should
 * never require touching anything but this header (and, for a Subaru, the
 * SSM2 seed table in MasterConfig.cpp).
 *
 * Everything in here is a COMPILED DEFAULT. The running values live in
 * MasterConfig and are editable from the portal; these tables are what a
 * fresh device starts from and what "restore defaults" returns to.
 */
#pragma once

#include <stdint.h>
#include <math.h>
#include "MasterPacket.h"

/* ═══════════════════════════════════════════════════════════════════════════
 *  HARDWARE WIRING (ESP32-S3 DevKit)
 * ───────────────────────────────────────────────────────────────────────────
 *  ESP32 GPIO 5  -> transceiver CTX/TXD      transceiver CANH -> OBD pin 6
 *  ESP32 GPIO 4  <- transceiver CRX/RXD      transceiver CANL -> OBD pin 14
 *  ESP32 3V3     -> transceiver VCC          OBD pin 16 (+12V) -> buck -> VIN
 *  ESP32 GND     -> transceiver GND          OBD pin 4/5 (GND) -> buck GND
 *
 *  The transceiver MUST be 3.3 V logic (SN65HVD230, TJA1051T/3). A 5 V part
 *  such as TJA1050 or MCP2551 drives its RX output above the ESP32's limit.
 *  On an SN65HVD230 tie RS to GND for high-speed mode.
 *
 *  Leave the module's 120 ohm termination OFF. The vehicle bus is already
 *  terminated at both ends and this node is a stub; a third terminator is the
 *  most common cause of a bus that half-works.
 *
 *  GPIO 4 doubles as the deep-sleep wake source (RTC-capable on the S3), so
 *  moving CAN_RX_GPIO means picking another RTC pin (GPIO 0-21).
 * ═══════════════════════════════════════════════════════════════════════════ */
#define CAN_TX_GPIO         5     /**< ESP32 TWAI TX  → transceiver CTX/TXD  */
#define CAN_RX_GPIO         4     /**< ESP32 TWAI RX  ← transceiver CRX/RXD  */
#define BOOT_BUTTON_GPIO    0     /**< The DevKit's BOOT button, active low:
                                       held 3 s, it switches a portal that
                                       was switched off (portal_on) back on. */
#define NIGHT_LDR_GPIO      6     /**< Optional LDR divider for night
                                       detection — see NIGHT_SOURCE below.
                                       Must be an ADC1 pin: on the ESP32-S3
                                       that is GPIO 1-10.                    */

/* ═══════════════════════════════════════════════════════════════════════════
 *  BUS PARAMETERS
 * ═══════════════════════════════════════════════════════════════════════════ */
/** CAN bitrate. Most OBD ports: 500 kbit/s. Body/comfort buses often 125 k. */
#define CAN_BITRATE_KBPS    500

/**
 * How the master talks to the ECU. See MasterConfig::diagMode.
 *
 *  AUTO   → listen first, then ask. Anything the car broadcasts is read from
 *           the bus. OBD-II is asked for what is not broadcast, and SSM2
 *           only for what OBD-II has no PID for (knock, A/F learning,
 *           switches). The learner keeps moving values onto the listening
 *           side, so requests shrink over time.
 *  SSM    → SSM2 requests only.  OBD → OBD-II requests only.
 *  SILENT → listen-only. The controller cannot ACK or transmit, so it is
 *           electrically incapable of disturbing the car; only the raw
 *           signal table produces data.
 */
#define DIAG_MODE_DEFAULT   DIAG_MODE_AUTO

/**
 * Seconds the master only listens after the car's bus comes up - at power-on,
 * on waking from sleep, and whenever the bus returns after going quiet (the
 * car switched off and on again) - before its first request. Every module is
 * starting at that moment; a request, or even an ACK, from us is one more
 * thing on a bus that is still settling. The car's own broadcasts are read,
 * and reach the displays, from the first frame. 0 turns the wait off.
 * Adjustable from the portal (start_delay_s).
 */
#define BUS_SETTLE_S        10

/** Broadcast cadence of the telemetry firehose. 40 ms = 25 Hz bursts. */
#define BROADCAST_PERIOD_MS 40

/**
 * A metric whose value has not changed is re-sent at least this often, so a
 * display that missed a burst, or was just switched on, never waits longer
 * than this for it. Must stay comfortably below the displays' stale timeout
 * (1500 ms) or an unchanging value would flicker to "--".
 */
#define BROADCAST_KEEPALIVE_MS 300

/** A metric older than this is dropped from the broadcast (master-side). */
#define METRIC_TTL_MS       1000
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

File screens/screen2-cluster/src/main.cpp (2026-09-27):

/**
 * @file main.cpp
 * @brief ESP32-S3 4.3" Dash Cluster (JC4827W543) — Slave Node entry point.
 *
 * Boot sequence:
 *   1. ConfigManager  — mount LittleFS, load layout.json
 *   2. DisplayManager — NV3041A (QSPI) + LVGL up
 *   3. TouchManager   — GT911 + gesture callbacks, measured touch mapping
 *   4. UIBuilder      — build screens from the layout
 *   5. NetworkManager — ESP-NOW listener on the telemetry channel
 *   6. Startup needle sweep, or the touch calibration wizard when the
 *      mapping has never been measured
 *
 * Runtime contexts:
 *   - Arduino loop : LVGL rendering, touch, web portal (config mode)
 *   - Wi-Fi task   : ESP-NOW receive → TelemetryStore (lock-protected)
 *
 * Controls:
 *   swipe left/right — change screen        swipe up   — day/night override
 *   tap              — toggle peak values   swipe down — reset peaks
 *   3 s touch hold   — enter config AP      3 s hold (in config) — reboot
 *   BOOT button tap  — next screen          BOOT button 2.5 s — config AP
 */
#include <Arduino.h>
#include <lvgl.h>

#include "HardwareConfig.h"
#include "ButtonManager.h"
#include "ConfigManager.h"
#include "DisplayManager.h"
#include "NetworkManager.h"
#include "TelemetryStore.h"
#include "TouchManager.h"
#include "UIBuilder.h"

/* ---- gesture wiring ------------------------------------------------------ */

/** @brief Swipe left / button tap — advance one screen. */
static void onSwipeLeft()  { UI.nextScreen(); }
/** @brief Swipe right — go back one screen. */
static void onSwipeRight() { UI.prevScreen(); }
/** @brief Swipe up — cycle the day/night override. */
static void onSwipeUp()    { UI.cycleNightOverride(); }
/** @brief Swipe down — reset every peak value. */
static void onSwipeDown()  { UI.resetPeaksWithToast(); }

/**
 * @brief Tap handler.
 *
 * While an alert is up a tap acknowledges it; otherwise it toggles the peak
 * readouts. Acknowledging takes priority so the gesture always means the most
 * urgent thing available.
 */
static void onTap() {
    if (!UI.acknowledgeAlert()) UI.togglePeaks();
}

/** @brief Calibration capture — hand the measured drag to the wizard. */
static void onRawDrag(int16_t dx, int16_t dy) { UI.onCalibrationDrag(dx, dy); }

/**
 * @brief Announce a GPIO that discovery saw change level.
 *
 * Surfaced as a toast rather than buried on the diagnostics screen, because
 * the whole point is that the user is pressing a button and needs to know
 * *immediately* whether anything responded — from whatever screen they happen
 * to be on.
 *
 * @param gpio The pin that deviated from its resting level.
 */
static void onButtonDiscovered(int gpio) {
    char msg[32];
    snprintf(msg, sizeof(msg), "BUTTON = GPIO %d", gpio);
    UI.showToast(msg);
}

/**
 * @brief Long-press handler — enter the config portal, or reboot out of it.
 *
 * Entering config mode hands the radio over: the ESP-NOW listener must stop
 * before the AP can come up, since the two cannot share the interface.
 */
static void onHold() {
    if (!Config.inConfigMode()) {
        // Radio handover: firehose listener out, Gauge Studio AP in.
        Net.stop();
        Config.enterConfigMode();
        UI.showConfigScreen(Config.apSsid(), Config.apIP().c_str());
    } else {
        ESP.restart();          // second long-hold applies config & reboots
    }
}

/* ---- lifecycle ----------------------------------------------------------- */

/**
 * @brief One-time bring-up.
 *
 * Order matters: the filesystem must be mounted before the UI can read the
 * layout, and the display must exist before UIBuilder can create objects on
 * it. The ESP-NOW listener starts last so no packets arrive before there is
 * somewhere to render them.
 */
void setup() {
    Serial.begin(115200);
    log_i("Telemetry Display v%s booting", FIRMWARE_VERSION);

    Config.begin();
    Telemetry.begin(Config.emaAlpha(), Config.staleMs());

    Display.begin();

    TouchManager::Callbacks cbs;
    cbs.onSwipeLeft  = onSwipeLeft;
    cbs.onSwipeRight = onSwipeRight;
    cbs.onSwipeUp    = onSwipeUp;
    cbs.onSwipeDown  = onSwipeDown;
    cbs.onTap        = onTap;
    cbs.onHold       = onHold;
    cbs.onRawDrag    = onRawDrag;
    Touch.begin(cbs, Config.touchCal(), Config.touchSwapXY(),
                Config.touchInvertX(), Config.touchInvertY(),
                Config.touchNativeW(), Config.touchNativeH());

    // Side BOOT button mirrors the two most useful touch actions, so the
    // display stays usable with gloves on.
    ButtonManager::Callbacks btn;
    btn.onShortPress = onSwipeLeft;
    btn.onLongPress  = onHold;
    btn.onDiscovery  = onButtonDiscovered;
    Button.begin(Config.buttonGpio(), Config.buttonDiscovery(), btn);

    UI.begin();
    Net.begin();

    /*
     * With no measured mapping there is no way to know which way a swipe
     * goes, so ask once rather than guessing and leaving one direction dead.
     * It costs two swipes and is never asked again.
     */
    if (!Config.touchCal().valid) UI.startTouchCalibration();
    else                          UI.startupSweep();

    log_i("Boot complete — free heap %u KB", ESP.getFreeHeap() / 1024);
}

/**
 * @brief Main loop: pump LVGL, poll the button, service the portal.
 *
 * Telemetry is not polled here — packets arrive on the Wi-Fi task and land in
 * the TelemetryStore, which the UI timer reads.
 */
void loop() {
    // lv_timer_handler returns the time until it next has work to do. Sleeping
    // exactly that long (capped) instead of a fixed 5 ms keeps animation frames
    // punctual when LVGL is busy, and still yields generously when it is idle.
    const uint32_t idleMs = Display.update();

    Button.poll();          // debounced BOOT button
    Config.loop();          // DNS + HTTP, only active in config mode

    delay(constrain(idleMs, (uint32_t)1, (uint32_t)10));
}

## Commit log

2026-09-25 Automotive telemetry: CAN master and two gauge screens
    One repository for the three firmware projects, reorganized as
    master/ plus screens/screen1-round and screens/screen2-cluster.
    - master: listen-first CAN decoding, OBD-II and SSM2 requests, the
    learner, bus guard, web portal, and the new power-on settle wait
    (start_delay_s, 10 s by default, adjustable in the portal)
    - screens: warning lamps, dash screen, redesigned cluster layout
    - host test harnesses for all three, with the car's saved config as
    a fixture so the "settings survive an update" check runs anywhere
    - library versions pinned to what the current builds use
    - CLAUDE.md, cloud-session setup hook and GitHub Actions CI
    Co-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
    [partitions_custom.csv]
2026-09-25 CI: one check per test suite, plus a sync check
    - scripts/check_sync.py enforces the "must stay in sync" rules from
    CLAUDE.md: MasterPacket.h identical in all three projects, the files
    the screens share identical, and generated files (master portal,
    studio metric catalogue, embedded studio page) matching their sources.
    It changes nothing and names the fix for each problem.
    - scripts/test_all.py runs sync, master, screen1 and screen2, prints a
    results table and writes it to the GitHub run summary.
    - CI runs each suite as its own check (Tests - sync/master/screen1/
    screen2) next to the three firmware builds, and attaches each screen's
    renders.
    - cloud-setup.sh installs PlatformIO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
2026-09-25 master: find and fix what sets P1718, with a TCM in the simulator
    The transmission ECU sets P1718 when the engine ECU's CAN messages stop
    reaching it. The simulator now has a TCM that watches those broadcasts and
    latches P1718, a marginal-link fault under which a normal-mode master
    error-flags (destroys) them, and a receive-error counter that winds down on
    good frames as a real controller's does. Run with the car's settings file,
    the TCM sets P1718 within seconds; the fixes stop it.
    Firmware, all adjustable, none touching a stored value (device_config still
    shows 0 differences, CFG_VERSION stays 5):
    - receive-error guard (rx_guard, rx_guard_rec): listen-only for the session
    when REC reach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
    [MasterConfig.cpp, MasterConfig.h, WebPortal.cpp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]
2026-09-25 master: close the guard-task gaps found auditing the MIL path
    An audit of every path that transmits, error-flags, switches controller
    mode or recovers from bus-off found four gaps, all in the bus guard task:
    - The switch to listen-only waited for the 2 s mode-switch throttle. The
    likeliest trip is in the first normal-mode contact with a marginal link,
    right after the settle wait - inside that 2 s. Towards listen-only the
    switch is now immediate (never while the controller is recovering from
    bus-off); only the way back is throttled.
    - Bus-off with the transmit guard off (the car's setting) recovered and
    carried straight on. It now latches listen-only until Resume; with both
    guard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
    [MasterConfig.cpp, MasterConfig.h, WebPortal.cpp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]
2026-09-25 screen 1: printable dash housing for the round display
    A parametric OpenSCAD housing for the ESP32-2424S012 board (ESP32-C3,
    1.28" GC9A01, CST816S touch) to stick on the dash: a cup the board drops
    into glass-first with three support pads, a side slot for the USB-C plug,
    teardrop holes for the two side buttons, vents and two magnet pockets in
    a flat back; a bezel ring on three M2 screws whose lip holds the glass on
    a foam ring; a 20-degree wedge base with a locating recess, matching
    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
    [base.stl, bezel.stl, cup.stl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]
2026-09-25 screen 1 housing: stand the puck upright on the dash top
    The mount is now a stand, like a gauge pod: the puck leans back 12 degrees,
    held by two magnets on a plate behind it and resting its bottom edge on two
    small lips, on a neck that leans with it down to a flat foot with the VHB
    pad pocket. The USB-C plug hangs from the puck's bottom, 9 mm clear of the
    foot, for a right-angle lead that goes sideways round the neck. The neck is
    a hull from the foot up to the back of the plate and its arms, so nothing in
    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
    [base.stl, round_display_housing.scad, stand.stl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]
2026-09-25 screen 1 housing: sleeker puck on a stalk, back-loading, no bezel ring
    The puck is now one bevelled piece with nothing on its face: the board
    goes in from the back against a front lip and a foam ring, and a flat
    cover with three posts closes it with three countersunk M2 screws into
    the wall. The stand is a Ø40 foot, a slim stalk that bends back into the
    puck's plane and a small dock with two magnets and a boss that drops into
    a recess in the cover, so nothing shows behind the puck and the boss
    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
    [bezel.stl, cover.stl, cup.stl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]
2026-09-26 master: make listen-only really silent (ESP32-S3 TWAI erratum)
    After the P1718 fix was flashed the car logged 100 000+ bus errors with
    the master listen-only, and the MIL came sooner than before; unplugged,
    no MIL. On the ESP32/S2/S3/C3 a listen-only TWAI controller still sends
    active error flags (Espressif erratum; ESP-IDF's fix,
    CONFIG_TWAI_ERRATA_FIX_LISTEN_ONLY_DOM, is off in the Arduino core), and
    listen-only freezes its error counters at the REC 0 twai_start() left.
    So it never went error-passive: on a frame it misread it destroyed every
    retransmission until the ENGINE ECU was driven bus-off - P1718. The
    settle wait and the receive-error guard had made listen-only the
    fallback exactly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
    [main.cpp]
2026-09-27 master: let errors pass, link instruments, and fixes from a full review
    Let errors pass (tx_passive, default on): the master never sends an error
    frame. twaiGoLive() keeps the TX pad off the controller through
    twai_start() - which clears the counters - until TEC is 220, for every
    start: boot, a mode switch, the bus-off restart. Portal: "Let errors pass",
    and "Safe bus settings" (/api/bus_defaults, MasterConfig::loadBusDefaults)
    puts the bus behaviour back to the defaults while keeping the bitrate,
    pacing, displays, Wi-Fi and everything learned.
    Where the errors come from: missed frames per periodic ID and mode
    (missAccount), and errors against the radio's air time (ESP-NOW send
    callback); p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
    [CanDecoderConfig.h, MasterConfig.cpp, MasterConfig.h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]
2026-09-27 screens: fixes from a full review, and a Gauge Studio that cannot hang
    Firmware (both boards unless noted):
    - Meters and charts run in integer units, so a fractional range moved in
    coarse steps (a -1..2 bar dial had four needle positions): values now go
    through GaugeBinding::unit, and tick labels are divided back.
    - lerp_speed clamped to 0.01-1 (above 2 the needles diverged).
    - An unreadable layout.json is kept as /layout.bad, not overwritten by the
    default; a layout without screens is refused by the studio's Save; a Save
    from a page opened before an on-device touch calibration keeps the
    device's calibration (cluster).
    - The config AP always starts: a channel, name or password it c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
    [partitions_custom.csv]
2026-09-27 check_sync: the studio's lamp symbols and colours; CLAUDE.md for the review
    check_sync.py now also checks what the studio page copies from the
    firmware: its ICONS are tools/telltale_icons.json, and every colour of its
    preview (PV, TONES) is a Palette.h colour - the round board's scheme stays
    the reference.
    CLAUDE.md: the portals are the only way into the settings (the AP limits,
    the fallback and the BOOT rescue), device_config replays every fixture,
    and which car file is which.
2026-09-28 Teach flashing turn signals and gear lever positions; more body values
    Teach by doing never found a turn signal: it wanted a bit that holds still
    through each step, and a flasher is lit for only half of the ON step. The
    census now counts every flip of every bit (masterCensusEdges, /api/bus?e=1),
    and a bit that sits still through both OFF steps and flips at least three
    times in the ON step is found as the flasher, however slowly the phone polls.
    Gear lever: Teach by doing gains a Positions mode (P R N D by default; M or
    3 2 1 can be added). A field that reads differently in every position is
    saved with a value table ("map":[[raw,value]] on a signal, RtSignal::nMap; a
    code not in the table pu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
    [MasterConfig.cpp, MasterConfig.h, WebPortal.cpp]
2026-09-29 Gear lever teaching: learn the lever as one combination of bits
    Positions mode took the lever as one contiguous field only when every bit
    that moved sat in one byte, and then from the lowest to the highest of them:
    a neighbour bit in that byte doing something else (a flag flickering beside
    the lever) spoiled every position's code, and positions spread over several
    bytes came back as one on/off value per position to be used one by one.
    Now the lever is the combination of every bit that moves with it, wherever
    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
2026-09-30 master: pin the listen-only TEC higher and again when it falls
    The S3 in the car read the listen-only TEC of 128 back as 127 straight
    after leaving reset mode ("listen-only erratum fix did not take"). With REC
    already known to wind down on good frames, the controller was error-active
    again while listening, and every misread became rounds of its own error
    flag - which the detached TX pad keeps off the bus, so it reads each one
    back recessive, calls it a bit error and flags again, each round counted.
    Harmless to the car, but it multiplied the error count (6906 errors for 886
    misreads in the new scenario with the old values).
    listenOnlyErratumFix() now writes TEC_LISTEN (200) and records what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
    [WebPortal.cpp, main.cpp]
2026-09-30 CLAUDE.md: what the car's master showed on 2026-09-30
    The listen-only counters do not hold on this S3 at all (bench boot: TEC and
    REC at 0 within milliseconds of the pin, applied again 75 times in 4 s), so
    the proposed fix is silent periods in normal mode with the TX pad
    detached. And the drive before the flash: 47 bus-offs in 155 s while
    polling with errors let pass - the master's own frames failing; the
    transmit path is the suspect.
2026-11-06 Portal teach rework, indicator run, lever field, lamp repeats, hazard arrows
    What all three devices run since 2026-09-30 evening:
    - portal: time-limited, one-at-a-time requests; no polling during a teach;
    clock-driven countdown; late readings dropped (teachSlot); idle
    preconnected sockets dropped by PortalServer
    - teach: left/right/hazard in one run; lever's own field preferred;
    taught signals replace what fed the value before (confirmed)
    - master: tolerant reading of bit-combination tables (nearestCode);
    on/off and position changes repeated in the next two bursts
    - screens: both arrows flash while the hazard switch is on
    - tests: portal_tests rewritten; lamp_radio_loss, lever_tolera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
2026-11-06 master: off means off - no frame left on a dead bus, quiet when the ECU is gone, off the bus across restarts
    A review of everything that transmits or switches the controller, against
    two questions: when the master is meant to be off the bus, is it really
    off; and when it transmits, does every frame go out properly.
    Confirmed sound (disassembled from the linked ESP-IDF): gpio_set_direction()
    routes the TX pad to the GPIO latch (SIG_GPIO_OUT_IDX), so listen-only with
    the pad detached cannot reach the bus whatever the controller does; the
    pad hold on GPIO5 is the RTC hold, which a software restart leaves in place.
    Fixed:
    - A frame nobody acknowledges - the car switched off under a request - w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
2026-11-06 master: trouble codes, calibration ID, oil change, G fallbacks and a drive log
    - Trouble codes: stored, pending and permanent (OBD-II 03/07/0A) from the
    engine computer (0x7E0) and the transmission computer (0x7E1, or 0x7DF
    with flow control to 0x7E1 if it never answers its own address). Read 8 s
    after the bus comes up, every dtc_poll_s (60 s; 0 = only when asked) and
    when the MIL or PID 01's count changes. Published to the displays as
    DTC_TOTAL and DTC_1..8; named from include/DtcText.h (shared, byte-
    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
2026-11-06 screens: code card, oil change lamp, G-meter and performance timers
    - The check-engine card names the codes the master read ("P1718 TCM 2/2",
    then what it means, scrolling when it does not fit), one every 3 s. A
    card-only "codes" lamp shows pending or leftover codes once with the car's
    lamp off, and lights no check-engine symbol on the strip or the dash.
    - "service" lamp: a new spanner symbol, amber 500 km before the oil change,
    "OVERDUE" after it.
    - gmeter screen: the car's acceleration as a dot in a friction circle.
    - perf screen: 0-100 km/h, 80-120 km/h and the quarter mile, timed here from
    the master's speed on the master's clock (TelemetryStore::stamped), each
    crossing inter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
2026-11-06 docs: codes, oil change, G-meter, drive log and timers
    Claude-Session: https://claude.ai/code/session_011GjV8kPoLPSQkVpmQq6R6K
2026-11-07 master: fixes from a full code review
    - Settings: LittleFS.begin(true) formatted the partition on the first
    failed mount, so one glitch at power-up erased the settings, every
    learned signal, the evidence log and the drive logs. Now mounted up to
    three times before formatting (only a blank partition is formatted),
    as the screens already do (config_mount_glitch, config_first_mount).
    - Trouble codes: a list whose reply was lost, or that met a busy bus,
    while the rest of the read worked dropped its codes from the screens
    and portal until the next read a minute later. Its codes are now kept
    for up to two reads, and a busy list is read again in 5 s
    (dtc_partial_read).
    - Trouble cod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
2026-11-07 master: TX/RX sweep against the ESP-IDF 4.4.7 driver and Espressif errata
    Checked the whole transmit/receive path against the v4.4.7 TWAI driver,
    HAL and GPIO sources, Espressif's chip errata (the S3 has none of the
    ESP32's twelve TWAI errata; only the listen-only one applies) and the
    restart code. Each bug below has a scenario that fails on the old code.
    - Listen-only "re-pin storm": twai_get_status_info() reports TEC = REC
    = 0 for any driver installed listen-only, whatever the controller
    holds. The guard read the counters through it and pinned TEC again
    every 50 ms - each time in reset mode, deaf to the bus. This is the
    2026-09-30 bench reading ("0 within milliseconds", 75 pins in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
2026-11-13 master: requests that landed inside an answer, and which PID is asked first
    A review of everything the master sends to the car. Each problem was
    reproduced in the simulator first; every scenario named here fails on
    the firmware before this commit.
    - The wait for an OBD-II answer ended at obd_to (25 ms on the car) and
    freed the bus for every requester at that moment. An ECU answering in
    35 ms was counted as silent - its PIDs backed off to a trickle - and
    in Auto the SSM2 engine put a 15-frame request into the window the
    ECU was answering in; the P2CAN wait held back the next OBD-II request
    only. The request that is waiting now keeps the bus until it is
    answered, refused, or obd_p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
